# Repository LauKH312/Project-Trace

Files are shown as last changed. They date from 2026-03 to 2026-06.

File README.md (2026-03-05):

# Project Trace
Multimeter-oscilloscope made for the DTU Bsc. Introductory Project

## Project Structure
```txt
project-root/
│
├── hardware/              # KiCad
│   ├── boards/
│   │   └── main_board/
│   ├── libraries/
│   │   ├── symbols/
│   │   ├── footprints/
│   │   └── 3dmodels/
│   └── fabrication/
│
├── firmware/
│   └── trace-cube/
│
├── docs/
│   ├── architecture/
│   ├── hardware/
│   ├── firmware/
│   ├── manufacturing/
│   └── user_manual/
│
├── scripts/               # build + automation tools
├── tools/                 # dev utilities (flashers, converters)
│
├── .gitignore
├── README.md
└── VERSION
```

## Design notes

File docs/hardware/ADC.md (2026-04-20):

# ADC
The choice of ADC was a great challenge due to the limitations of microcontrollers. 
Available ADCs which sample in the tens of MS/s were to a high extent reliant on Serial LVDS, Parallel LVDS,  Serial CMOS interfaces, all of which are not available to us due to the limitations of microcontrollers.
With a greater amount of development time, the problem can be solved using an FPGA. Due to our serious time constraints this is out of the question.

Initially we had wanted to use only one ADC (the front-runner was the ADS1605). 
Later we chose to solve the problem by compromising on bit width, keeping a second ADC with high precision and no strict speed requirements for DC and slow AC measurements.%% The faster-sampling less precise ADC is named **AC-ADC** and the slower highly precise ADC is named the **DC-ADC**. %%
Due to time and cost constraints we had to revert to using one  ADC, compromising instead on speed.

%% The loss of precision for the AC-ADC is remedied by adding new elements to the signal conditioning, allowing greater voltage resolution. This includes variable offset (requiring a precise DAC),  AC coupling and more gain settings for the InAmp. 
 %%

## ADC
We identified the following ADCs to be the most suitable candidates for the AC-ADC.

| **PARAMETER** | **ADS1605** | ADS1602  | AD4001BRMZ | **ADC3542(ADC3543)** | **ADS850** |
| --- | --- | --- | --- | --- | --- |
| **Max Sampling Rate** | 5 MS/s | 2.5 MS/s | 2 MS/s | 25(65) MS/s | 10 MS/s |
| **Bit Width** | 16b | 16b | 16b | 14b | 14b |
| **VDD** | 5V | 5.0V | 1.8V | 1.8V | 5.0V |
| **VDDIO** | 3.3V | 3.3V | 3.3V | 1.8V | 3.3V |
| **Interfaces** | PCMOS | SPI | SPI | SDR,DDR,PCMOS | PCMOS |
| Cost (no VAT) | 387DKK | 151DKK | 145DKK | | |

%% In terms of bandwidth the ADC3542/ADC3543 is the superior option, providing the possibility of sampling the fastest. It is due to the need for special signal conditioning and logic level shifting needed to accommodate its 1.8V supply that it was rejected. 
Second best is the ADS850, which we initially chose, due to its okay-ish sample-rate and its easy integration, which made it suitable for this project.
The AD850 is beat by the ADS1605 on bit-depth and not surprisingly on SNR as a result. Our hope is that the extra signal conditioning will make this difference insignificant in most applications.
 %%
The 14b options were only seriously considered when designing the dual-ADC version, however using a single ADC, the low bit-depth is considered too limiting for the precision of DC measurements.
d

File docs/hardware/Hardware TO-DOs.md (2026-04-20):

# TO-DO List - Hardware
## General
- [ ] Create and assign handsolder versions for all used applicable footprints
- [x] Assign Digikey Partnumbers to all parts ordered from Mouser
%% - [ ] Consider using Global Sourcing for Mouser Parts for PCBA %%
%% - [ ] Assign JLCPCB Partnumbers to all parts ordered for assembly %%
## Front-End
### Inputs & InAmp
- [-] Decide new gain-setting/settings
- [-] Compensate for on-resistance of switches?
- [x] Design AC-Coupling Circuit
- [x] Implement circuit using new 
## Digital
### ADC
- [x] Find voltage references

- Decided against creating a external clock source.
### User Interface
- [x] Decide upon interface
Use two rotary encoders,  two pushbuttons (off-(on)), power switch. Visual feedback with screen (128x64).
- [x] Integrate display
- [x] Connect buttons and encoders

### MCU
- [x] Decide which Nucleo board to use
- [x] Create Symbols
- [x] Create Footprint
- [x] Find SRAM IC
- [x] Create symbol and footprint for SRAM if necessary
## Power
_With BMS_
- [x] Decide on battery charging solution
- [x] Add screw-terminals

## Docs
- [ ] Update docs where applicable (rev2)

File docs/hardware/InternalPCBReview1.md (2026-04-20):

# Internal PCB Review 1
## Before Submitting Your Board for PCB Design Review
- [x] Check for unrouted nets
- [x] Repour all polygons
- [?] Ensure your board has a complete silkscreen, including:
	- [-] Company logo(s)
	- [?] Product logo(s)
	- [-] Copyright notice
	- [-] Warning/Hazard label(s) and Icons
	- [x] Connectors are labeled, and pinouts are called out where relevant
	- [-] QA/Test block with barcode, blank areas for a serial number, dates, and QA/Test checkmarks
	- [x] Board name, print date, and revision number
- [!] If there are designators on the silkscreen, then check:
	- [!] Each designator is close to and clearly identifies the associated component
		- C316-C321 messy
		- C336 intersects
		- JP303 intersects
		- TP201 (VCOM) silkscreen intersect
		- R311
	- [x] All designators are only in one or two orientations
	- [x] Text size and font will remain legible after the fabrications process
	- [!] ICs have pin one clearly marked, i.e., the pin one marker is not located under another component
		- U305 unclear
		- U306 might be unclear
		- U205 ambiguous
- [x] Update the PCB from its schematics to ensure the schematic and board are synchronized
- [x] Ensure the design rule report passes with no errors
- [?] Ensure there is a design rule to catch nets with only 1 pin
- [?] Ensure you have the board outline on a mechanical layer that will go to the board fabricator
- [-] Fiducials are present for the assembly and meet these criteria:
  - [-] Three board-level fiducials are included as a minimum
  - [-] Two fiducials are diagonally opposing each other across all extremely fine-pitch components
- [-] Mounting points have sufficient clearance for the chosen washer and screw head
- [-] If an enclosure model is available, it has been tested against the board to ensure there will be no interference between the enclosure and components
- [-] All components (including mechanical items) have accurate 3D models

## Layers
- [x] Check the layer stack and substrate heights meet the fabricator's specifications (or that the fabricator can meet your specifications)
- [x] Check the copper thickness on all layers matches the target fabricator's specifications (or that there is a callout on the documentation layer for the required copper thickness)
- [x] Ensure there is at least one continuous, unbroken ground plane
- [-] If your board has controlled impedance nets, they are correctly set up both on the layer stack and in the design rules
- [x] Check if any keep-out track matches the board shape
- [?] Check any board cutouts or slots used for a keep-out barrier to prevent nets from crossing milled areas
	- GND Plane cut under ADC?

// A PCB stackup table that was created as part of your front-end engineering specifications can be helpful here as it gives a visual comparison with the data in your PCB editor. A table provided by your fabrication house or manufacturer is the best resource, such as the example shown below.

## Signal Path
- [!] Ensure that the ground plane has sufficient current-carrying vias near connectors, and voltage/return sinks
	- Connector could use more
- [-] If required/relevant, ensure voltage planes and areas have sufficient connection vias for current requirements
- [x] Ensure tracks to reference planes are sufficiently wide for current requirements
- [x] Check there are sufficient quantities of vias for the current-carrying capacity of traces
- [x] Check the minimum track widths for all current-carrying nets are sufficient. Consider if a design rule is required
	- 3V3 track about the 'coupling' text can be made wider
	- 3V3 track above JP301 label has a sharp corner
- [x] Check all ground pins have a via to the ground plane
- [x] Check there is a continuous ground plane within one signal layer of any signal trace
- [-] Check any controlled impedance traces have the correct net rules and impedance profile
- [-] Check differential pair tracks are as close together as possible
- [-] Check differential pair tracks lengths are matched
- [-] Check all high-speed signals are length matched, specifically including:
  - [-] DDR
  - [-] PCIe
  - [-] Ethernet
  - [-] LVDS
  - [-] HDMI
  - [-] USB3+
  - [-] MIPI
- [-] Check every signal trace has a constant impedance along its length. If the trace changes layer, its impedance should stay the same
- [-] Check traces longer than 1/6th of the rise or fall time of the signal have been simulated:
- [!] Check termination resistors, or another termination is present to prevent ringing or overshoots
	- ADC SCLK, DOUT, FSO lacks termination
	- SPI3 SCLK, MOSI
- [ ] Check termination resistors are in the relevant locations
- [-] Check long traces that hug other traces that have been simulated for crosstalk
	- Display traces can be spaced more before conn
- [x] Check all high-speed traces run over a continuous ground pour
- [x] Ensure that no sensitive nets run under noisy components
- [x] Check that the vias for decoupling capacitors are not shared
- [x] Each decoupling capacitor requires its own via for VCC and for GND direct to reference planes

## Components
- [x] Check all through-hole pads are set to plated if they are going to be soldered
- [ ] Check there is sufficient clearance for the following:
  - [-] For pick and place heads in production
  - [ ] For hand assembly in prototypes
  - [ ] For soldering pen tip access if any rework is required
- [x] Check bypass capacitors are placed as close to IC power pins as possible (under 15mm)
- [!] Check crystal/oscillator clock sources are as close to the IC clock pins as possible
- [!] Check termination resistors are as close to the signal source as possible
- [-] Check EMI/RFI filtering is as close to the exit point (board edge, connector, shield) as possible
- [-] Check potentiometers increase signal/voltage when turned clockwise
- [ ] Check programmable devices have accessible programming header/pads
- [-] Check no high thermal mass components (e.g., large transformers/inductors) are located next to very small components
- [ ] Check component placement prioritizes short track lengths for high-speed signals
- [-] Check there are a sufficiently large copper area for heat-sinking high-dissipation devices, including:
  - [ ] Linear regulators
  - [-] Switched-mode power supplies (including LED drivers)
  - [-] High power LEDs
  - [-] High-frequency gate drivers
  - [-] MOSFETs
  - [-] Motor drivers
  - [-] Chargers
  - [-] High-speed microprocessors
  - [-] Power amplifiers

## Testing
- [x] Check that test pads are sufficiently far from the edge of the board to allow fixturing
- [-] Check test pads do not create stubs/impedance mismatch on high-speed nets
- [x] Check that component do not obstruct access to test pads for manual testing (e.g., using an oscilloscope probe) or automated testing (e.g., using a bed of nails)
- [x] Check test pads are clearly labeled for prototypes
- [!] Check any signal needed for testing or inspection has a test point
	- 3V3, 5V missing test points...
- [x] Check test points are all located on the same side of the board, ideally:
  - [-] The bottom of the board for access using a bed of nails fixtures
  - [x] The top of the board for manual access with test equipment (e.g., oscilloscope probes)

## Protection/EMI/EMC
- [-] Check appropriate creepage and clearance rules are set for all high-voltage nets
- [x] Check if separate earth tracks/paths are necessary for ESD
- [x] Check there are decoupling capacitors next to connectors and vias that may require them
- [x] Check TVS diodes or other ESD mitigation component pads are in series with the track to the component (i.e., any ESD event must pass through the component pad before getting to a sensitive device)
- [ ] Ensure there are no track stubs/net antennas going to test points or unused connector pins
- [ ] Ensure high-speed signals are routed as directly as possible—no scenic routes
- [x] Check any track carrying over 100mA has its width calculated to ensure it is of sufficient size for the current
- [ ] If the board will be fitted within an enclosure with little or no airflow, calculate or simulate the width for an internal layer instead of an external layer
- [ ] Check if an RF shield is required anywhere on the board and if it has a sufficient footprint
- [-] If you are using a two-layer board:
	- [-] Are there any ground loops?
	- [-] Is there a ground track of sufficient size for the return current of every device?
	- [-] Is there an unbroken ground pour under every high-speed trace?
	- [-] If you have multiple grounds, ensure that they are tied together at a single point only

## Panels
- [-] Ensure that there is sufficient frame area for conveyors and clamping
- [ ] Ensure that the silkscreen includes the following:
- [-] Blanks for QA/Testing marks
- [ ] Print date
- [-] Machine name
- [-] Company name
- [-] Panel barcode
- [x] Board part number and revision
- [-] Check panel fiducials are present
- [-] Check for an origin identification mark
- [-] Check impedance/layer/other test areas are present if required
- [-] Check V Score/Milling/tab layers are present and aligned with the board if they are not in the board file
- [?] Check the panel isn't too large for the board thickness and any milling (i.e., low flexibility/bounce)

## Comments
- Reassign designators?
- Maybe write pin-out to connector?
- Ensure Correct Orientation of Screw Terminal
- PCB legs
- Eliminate gnd fill antennas - swiss-cheese the thing
- 220R Resistors (for LED) are missing PN and Footprint - ignore PN if using resistors from lab.
- Extra GND via to U306

- AAF coeff

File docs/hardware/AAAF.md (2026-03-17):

# Analog Anti-Aliasing Filter
There is an open question regarding the topology and design of the AAAF. Initially we favoured a Type II Chebyshev filter, however upon learning that this cannot be implemented on a Sallen-Key topology, we reconsider the filter design, or choose to implement it using a passive Cauer topology.
The options are as follows
- Type II Chebyshev filter implemented on a Cauer topology
- Type I Chebyshev filter implemented on a Sallen-Key topology
- Bessel filter implemented on a Sallen-Key Topology

| Type II Cheby - Cauer | Type I Cheby - Sallen-Key | Bessel - Sallen-Key |
| --- | --- | --- |
| No passband ripple | Little (possibly negligible) passband ripple | |
| | | Linear phase response |
| Possibly lower order | | Highest order solution |
| High susceptibility to component deviations (inherent to LC ladder) | Lesser susceptibility to component deviations<br>(0.1% Thin-Film R, 1% NP0 cap) | Lesser susceptibility .... |
| Not Effected by Op-Amp Bandwidth | | |
| | | |

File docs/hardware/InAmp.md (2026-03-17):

# Instrumentation Amplifier
We chose the Analog Devices AD8421 due to its high bandwidth (10MHz@G=0dB) and because we have SPICE models, which we can use for simulation. We considered assembling our own InAmp from higher bandwidth precision op-amps and diff-amps, but chose against this due to uncertainties around component tolerances. It also was unclear whether the higher bandwidth would be spent when chaining together multiple amps.

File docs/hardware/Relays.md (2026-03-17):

# Relays
We had a choice between electromechanical relays and solid-state relays.

| Electromechanical Relay | Solid-State Relay |
| --- | --- |
| Low on resistance $R_{on} < 500\mathrm{m\Omega}$ | Higher on-resistance $>2 \Omega$ |
| Can block high voltages | ~~Generally limited by voltage~~ |
| Large | Roughly SOIC-Sized |
| Switching requires special consideration | Switchable with GPIO |
| | |
Due to the large resistances in the attenuator we deemed the 2R5 on resistance of the Panasonic AQW280SX to be negligible, however the ammeter uses a 100m shunt resistor, which would be greatly impacted by this. We chose to buffer the voltage over the shunt-resistor to eliminate this probem.

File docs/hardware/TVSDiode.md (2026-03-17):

# TVS Diode
According to a brief search on Mouser, many TVS have a leakage around $1\mathrm{\mu A}$.
For the ammeter this is a non-issue, as this is many orders of magnitude under the maximum of 200mA in the range.

However in the voltmeter this poses an issue

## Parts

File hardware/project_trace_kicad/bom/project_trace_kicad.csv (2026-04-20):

Reference | Value | Qty | Extra | DigikeyPN | DNP | Exclude from BOM | Exclude from Board | Footprint | Datasheet | MouserPN
U305 | 625L3C040M00000 | 1 |  | 110-625L3C040M00000CT-ND |  |  |  | ProjectTraceFootprints:IC_625L3C040M00000_CTS-M
R211 | 8k98 | 1 | 0.1% | 13-RT0603BRD078K98LCT-ND |  |  |  | Resistor_SMD:R_0603_1608Metric_Pad0.98x0.95mm_HandSolder
R205,R213 | 193R | 2 |  | 13-RT0603DRE07193RLCT-ND |  |  |  | Resistor_SMD:R_0603_1608Metric_Pad0.98x0.95mm_HandSolder
D201 | SMAJ250A | 1 |  | 13-SMAJ250A/TR13CT-ND |  |  |  | Diode_SMD:D_SMA_Handsoldering
U302 | MCP6499T | 1 |  | 150-MCP6499T-E/SLCT-ND |  |  |  | ProjectTraceFootprints:SOIC-14_3.9x8.7mm_P1.27mm_Handsolder | http://www.ti.com/lit/ds/symlink/lm2902-n.pdf
R305,R307 | 37k | 2 |  | 2019-RN73R1JTTD3702F100CT-ND |  |  |  | Resistor_SMD:R_0603_1608Metric_Pad0.98x0.95mm_HandSolder
R212 | 111R | 1 |  | 2019-RN73R1JTTD1110B25CT-ND |  |  |  | Resistor_SMD:R_0603_1608Metric_Pad0.98x0.95mm_HandSolder
R201 | 100m | 1 | 0.5% 1W5 | 2019-SLW1TTER100DCT-ND |  |  |  | Resistor_SMD:R_2512_6332Metric_Pad1.40x3.35mm_HandSolder | https://www.koaspeer.com/pdfs/SLW07-SLW1-SLN3-SLN5.pdf#page=1.00 | SLW1TTER100D
PH501,PH502 | PH for Nucleo | 2 |  | 2057-PH2-80-UA-ND |  |  | Excluded from board
U203 | AQW280SX | 1 |  | 255-5713-1-ND |  |  |  | ProjectTraceFootprints:AQW282SX | https://www.mouser.com/catalog/specsheets/AQW280S[1].pdf | 769-AQW280SX
U204 | AQW282SX | 1 |  | 255-AQW282SXCT-ND |  |  |  | ProjectTraceFootprints:AQW282SX | https://mm.digikey.com/Volume0/opasdata/d220001/medias/docus/2807/AQY%2CW28xS_DS.pdf
U202 | SN74LVC2G14DBV | 1 |  | 296-13010-1-ND |  |  |  | Package_TO_SOT_SMD:SOT-23-6_Handsoldering | https://www.ti.com/lit/ds/symlink/sn74lvc2g14.pdf
U401 | UA78M33QDCYRQ1 | 1 |  | 296-13424-1-ND |  |  |  | Package_TO_SOT_SMD:SOT-223-3_TabPin2 | https://www.ti.com/lit/gpn/UA78M-Q1
U303 | ADS1602 | 1 |  | 296-17890-1-ND |  |  |  | ProjectTraceFootprints:LQFP-48_7x7_Pitch0.5mm - PFB0048A | https://www.ti.com/lit/ds/symlink/ads1602.pdf
U206 | TS5A23159DGS | 1 |  | 296-18598-1-ND |  |  |  | Package_SO:TSSOP-10_3x3mm_P0.5mm | http://www.ti.com/lit/ds/symlink/ts5a23159.pdf
U205,U207 | OPA2837IRUNT | 2 |  | 296-53042-1-ND |  |  |  | ProjectTraceFootprints:OPA2837IRUNT-Handsolder
U201 | TLE2426xLP | 1 |  | 296-TLE2426CLPRCT-ND |  |  |  | Package_TO_SOT_THT:TO-92_Inline_Wide | http://www.ti.com/lit/ds/symlink/tle2426.pdf
C316,C317,C318 | 100p | 3 | C0G | 311-1069-1-ND |  |  |  | Capacitor_SMD:C_0603_1608Metric_Pad1.08x0.95mm_HandSolder
C213 | 680p | 1 | C0G | 311-1425-1-ND |  |  |  | Capacitor_SMD:C_0603_1608Metric_Pad1.08x0.95mm_HandSolder
C211 | 300p | 1 | C0G | 311-3967-1-ND |  |  |  | Capacitor_SMD:C_0603_1608Metric_Pad1.08x0.95mm_HandSolder
C202,C205,C208,C210,C214,C305,C307,C310,C311,C313,C314,C315,C319,C320,C321,C324,C326,C327,C328,C331,C334,C338,C339 | 100n | 23 | 25V | 399-C0603C104K3RACTUCT-ND |  |  |  | Capacitor_SMD:C_0603_1608Metric_Pad1.08x0.95mm_HandSolder
C301,C302,C306,C308,C312,C325,C329,C335,C337 | 1u | 9 | 16V | 399-C0603C105K4RACTUCT-ND |  |  |  | Capacitor_SMD:C_0603_1608Metric_Pad1.08x0.95mm_HandSolder
R202 | 1M8 | 1 | 0.1% | 408-2026-1-ND |  |  |  | Resistor_SMD:R_0805_2012Metric_Pad1.20x1.40mm_HandSolder
C201,C203,C204,C207,C209,C212,C303,C309,C322,C323,C330,C333,C336 | 10u | 13 |  | 490-10516-1-ND |  |  |  | Capacitor_SMD:C_0805_2012Metric_Pad1.18x1.45mm_HandSolder
C206 | 10u | 1 | X7R | 490-10516-1-ND |  |  |  | Capacitor_SMD:C_0805_2012Metric_Pad1.18x1.45mm_HandSolder
U301 | ADA4950-1 | 1 |  | 505-ADA4950-1YCPZ-R7CT-ND |  |  |  | ProjectTraceFootprints:ADA4950-QFN-16_EP_3.1x3.1_Pitch0.5mm | https://www.analog.com/media/en/technical-documentation/data-sheets/ADA4950-1_4950-2.pdf
U402 | AMS1117-5.0 | 1 |  | 5272-AMS1117-5.0CT-ND |  |  |  | Package_TO_SOT_SMD:SOT-223-3_TabPin2 | http://www.advanced-monolithic.com/pdf/ds1117.pdf
U304 | LM4040DBZ-4.1 | 1 |  | 576-2568-1-ND |  |  |  | Package_TO_SOT_SMD:SOT-23_Handsoldering | http://www.ti.com/lit/ds/symlink/lm4040-n.pdf
J204,J403 | Screw_Terminal_01x04 | 2 |  | 732-691210910004-ND |  |  |  | ProjectTraceFootprints:691210910004 |  | 710-691210910004
DZ201,DZ202 | EZA-EG3A50AV | 2 |  | P13682CT-ND |  |  |  | Diode_SMD:D_0603_1608Metric_Pad1.05x0.95mm_HandSolder |  | 667-EZA-EG3A50AV
J205 | Conn_Coaxial | 1 |  | WM14063-ND |  |  |  | ProjectTraceFootprints:BNC_Female_0731385003
R209,R303,R304,R601,R602,R603,R604 | 10k | 7 |  | YAG1236CT-ND |  |  |  | Resistor_SMD:R_0603_1608Metric_Pad0.98x0.95mm_HandSolder
R206,R208,R210 | 1k | 3 | 0.1% | YAG1237CT-ND |  |  |  | Resistor_SMD:R_0603_1608Metric_Pad0.98x0.95mm_HandSolder
R203,R311 | 180K | 2 | 0.1% | YAG1548CT-ND |  |  |  | Resistor_SMD:R_0603_1608Metric_Pad0.98x0.95mm_HandSolder
R204 | 20K | 1 | 0.1% | YAG1582CT-ND |  |  |  | Resistor_SMD:R_0603_1608Metric_Pad0.98x0.95mm_HandSolder
R301,R302,R306,R308,R309,R310,R501,R504,R505 | 24R9 | 9 |  | YAG4511CT-ND |  |  |  | Resistor_SMD:R_0603_1608Metric_Pad0.98x0.95mm_HandSolder

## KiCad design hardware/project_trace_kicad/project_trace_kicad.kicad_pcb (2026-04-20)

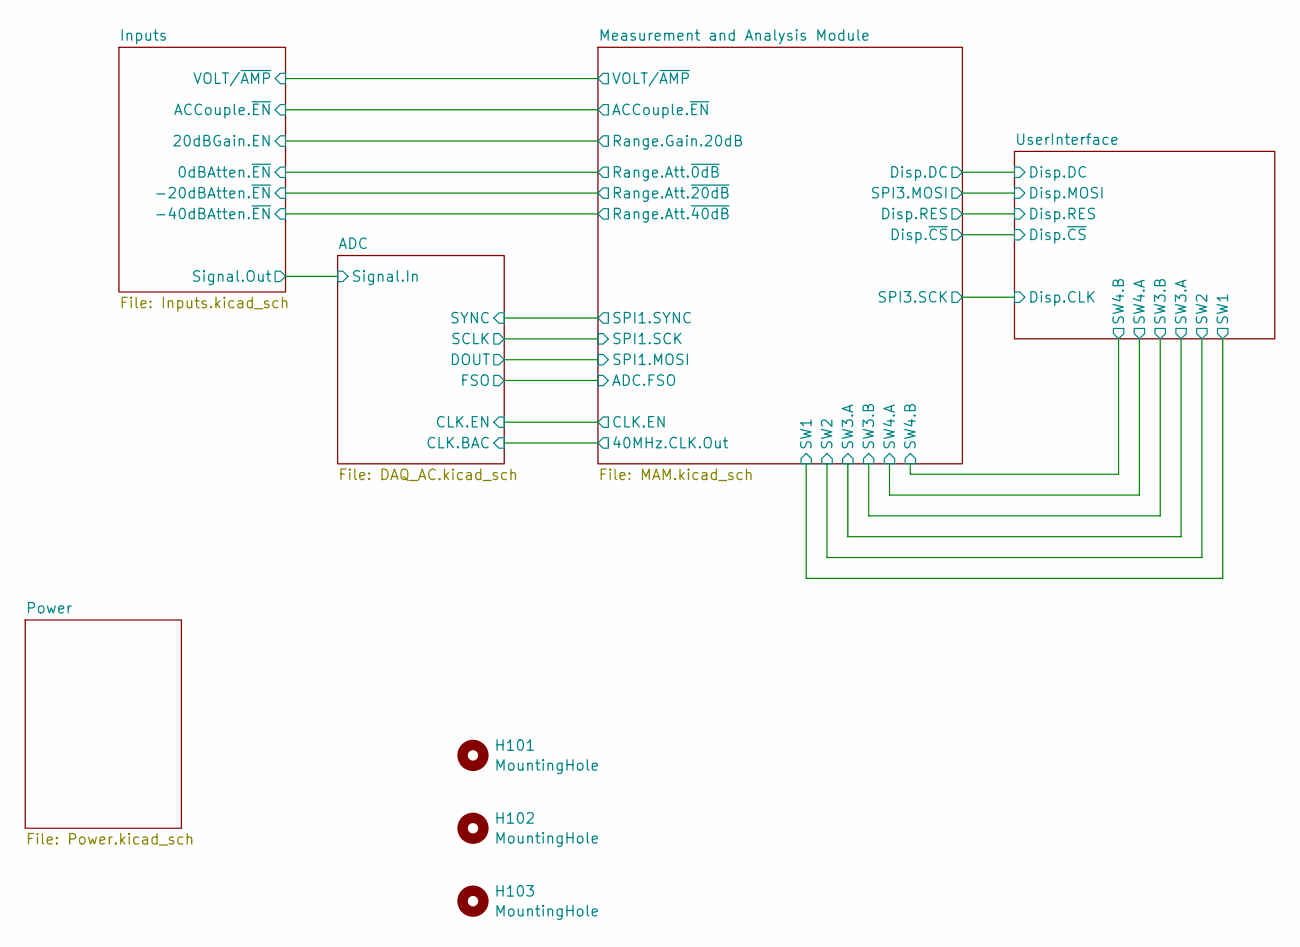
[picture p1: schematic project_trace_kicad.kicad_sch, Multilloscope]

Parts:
H101, H102, H103: MountingHole; MountingHole_4.3mm_M4_DIN965; DigikeyPN N/A

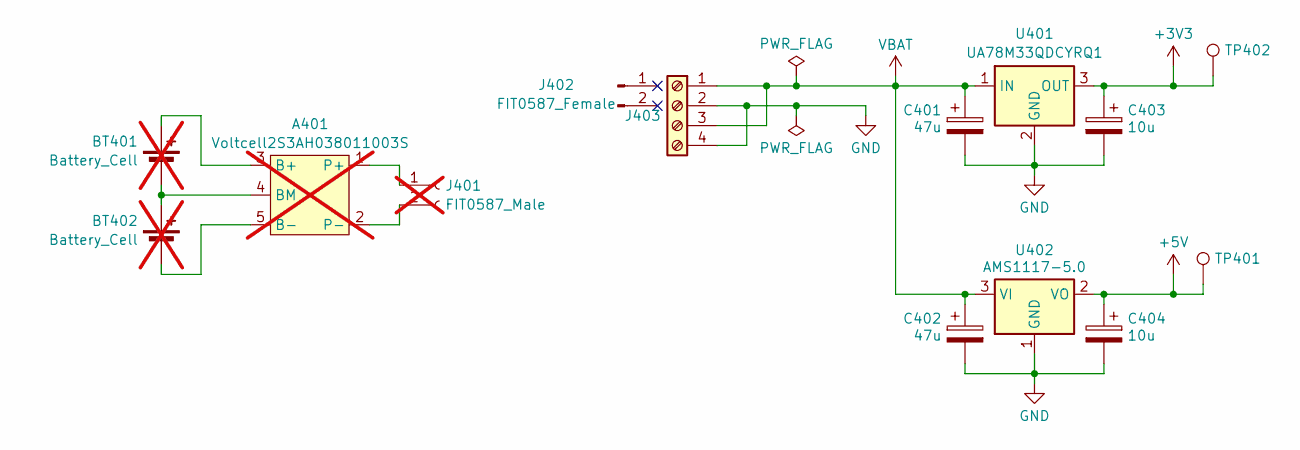
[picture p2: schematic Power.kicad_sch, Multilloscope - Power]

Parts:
A401: Voltcell2S3AH038011003S; DigikeyPN N/A; not fitted
BT401, BT402: Battery_Cell; DigikeyPN N/A; not fitted
C401, C402: 47u; CP_Radial_D6.3mm_P2.50mm; DigikeyPN N/A
C403, C404: 10u; CP_Radial_D6.3mm_P2.50mm; DigikeyPN N/A
J401: FIT0587_Male; DigikeyPN N/A; not fitted
J402: FIT0587_Female; DigikeyPN N/A
J403: Screw_Terminal_01x04; 691210910004; DigikeyPN 732-691210910004-ND
TP401, TP402: TestPoint; TestPoint_Pad_1.5x1.5mm; DigikeyPN N/A
U401: UA78M33QDCYRQ1; SOT-223-3_TabPin2; DigikeyPN 296-13424-1-ND
U402: AMS1117-5.0; SOT-223-3_TabPin2; DigikeyPN 5272-AMS1117-5.0CT-ND

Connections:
+3V3: C403.1, TP402.1 (1_1), U401.3 (OUT); also elsewhere on the board
+5V: C404.1, TP401.1 (1_1), U402.2 (VO); also elsewhere on the board
GND: C401.2, C402.2, C403.2, C404.2, J403.2, J403.4, U401.2 (GND), U402.1 (GND); also elsewhere on the board
unnamed: A401.1 (P+), J401.1
unnamed: A401.2 (P-), J401.2
unnamed: A401.3 (B+), BT401.1 (+)
unnamed: A401.4 (BM), BT401.2 (-), BT402.1 (+)
unnamed: A401.5 (B-), BT402.2 (-)
VBAT: C401.1, C402.1, J403.1, J403.3, U401.1 (IN), U402.3 (VI)

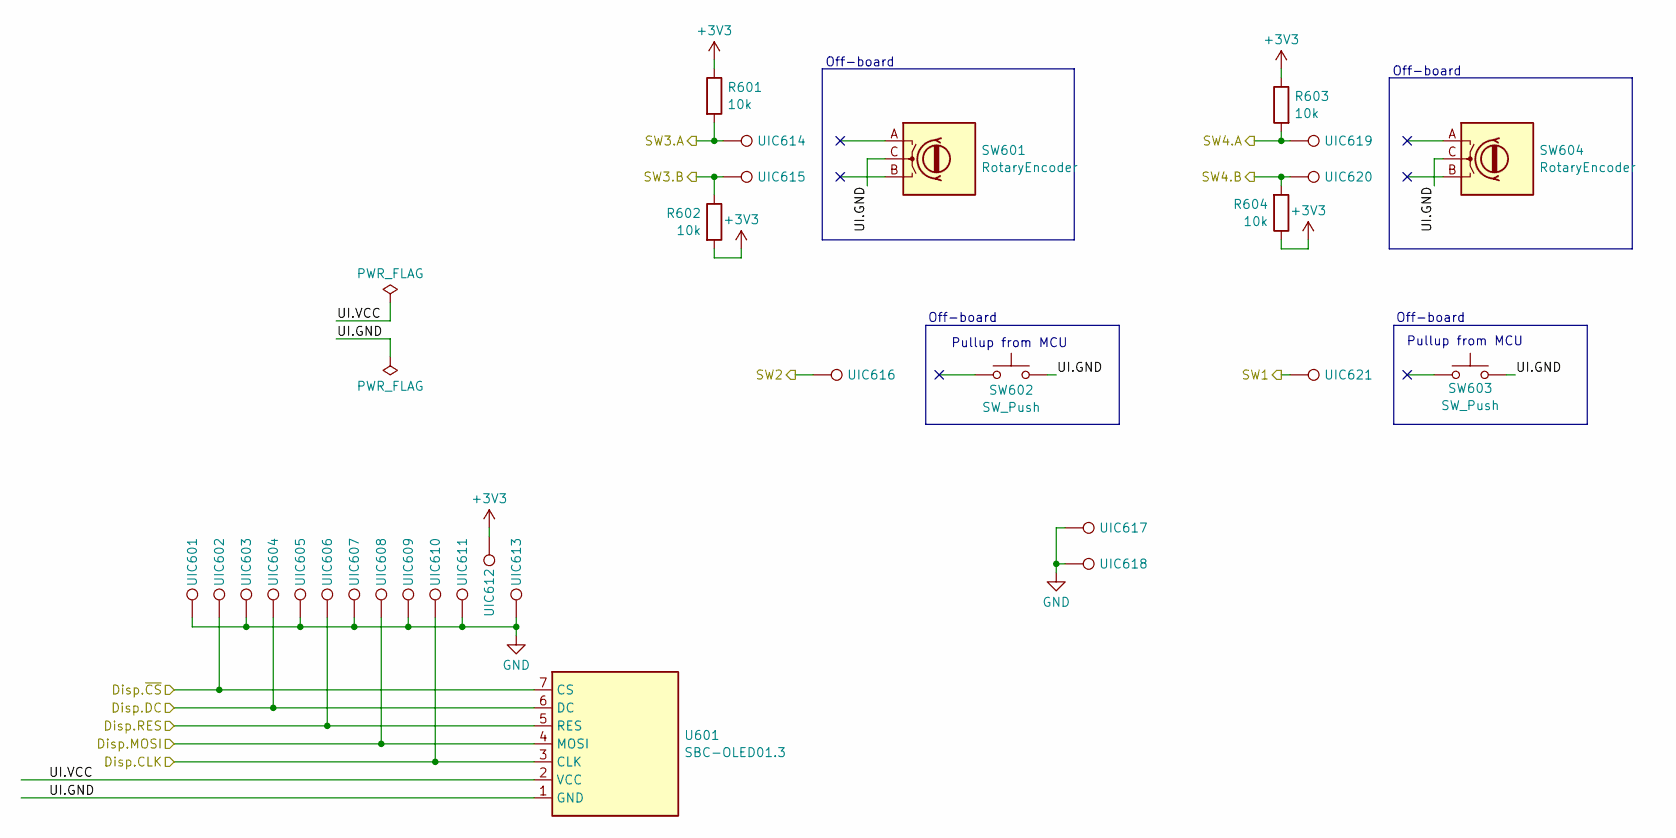
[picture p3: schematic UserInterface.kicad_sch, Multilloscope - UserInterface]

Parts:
R601, R602, R603, R604: 10k; R_0603_1608Metric_Pad0.98x0.95mm_HandSolder; DigikeyPN YAG1236CT-ND
SW601, SW604: RotaryEncoder; DigikeyPN N/A
SW602, SW603: SW_Push; DigikeyPN N/A
U601: SBC-OLED01.3; DigikeyPN N/A
UIC601, UIC602, UIC603, UIC604, UIC605, UIC606, UIC607, UIC608, UIC609, UIC610, UIC611, UIC612, UIC613, UIC614, UIC615, UIC616, UIC617, UIC618, UIC619, UIC620, UIC621: UIconnector; TestPoint_Pad_D2.5mm; DigikeyPN N/A

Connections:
+3V3: R601.1, R602.2, R603.1, R604.1, UIC612.1 (1_1); also elsewhere on the board
/Measurement and Analysis Module/Disp.DC: U601.6 (DC), UIC604.1 (1_1); also elsewhere on the board
/Measurement and Analysis Module/Disp.RES: U601.5 (RES), UIC606.1 (1_1); also elsewhere on the board
/Measurement and Analysis Module/Disp.~CS: U601.7 (CS), UIC602.1 (1_1); also elsewhere on the board
/Measurement and Analysis Module/SPI3.MOSI: U601.4 (MOSI), UIC608.1 (1_1); also elsewhere on the board
/Measurement and Analysis Module/SPI3.SCK: U601.3 (CLK), UIC610.1 (1_1); also elsewhere on the board
/Measurement and Analysis Module/SW1: UIC621.1 (1_1); also elsewhere on the board
/Measurement and Analysis Module/SW2: UIC616.1 (1_1); also elsewhere on the board
/Measurement and Analysis Module/SW3.A: R601.2, UIC614.1 (1_1); also elsewhere on the board
/Measurement and Analysis Module/SW3.B: R602.1, UIC615.1 (1_1); also elsewhere on the board
/Measurement and Analysis Module/SW4.A: R603.2, UIC619.1 (1_1); also elsewhere on the board
/Measurement and Analysis Module/SW4.B: R604.2, UIC620.1 (1_1); also elsewhere on the board
GND: UIC601.1 (1_1), UIC603.1 (1_1), UIC605.1 (1_1), UIC607.1 (1_1), UIC609.1 (1_1), UIC611.1 (1_1), UIC613.1 (1_1), UIC617.1 (1_1), UIC618.1 (1_1); also elsewhere on the board
unnamed: SW601.C, SW602.1, SW603.2, SW604.C, U601.1 (GND)

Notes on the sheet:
Pullup from MCU
Off-board

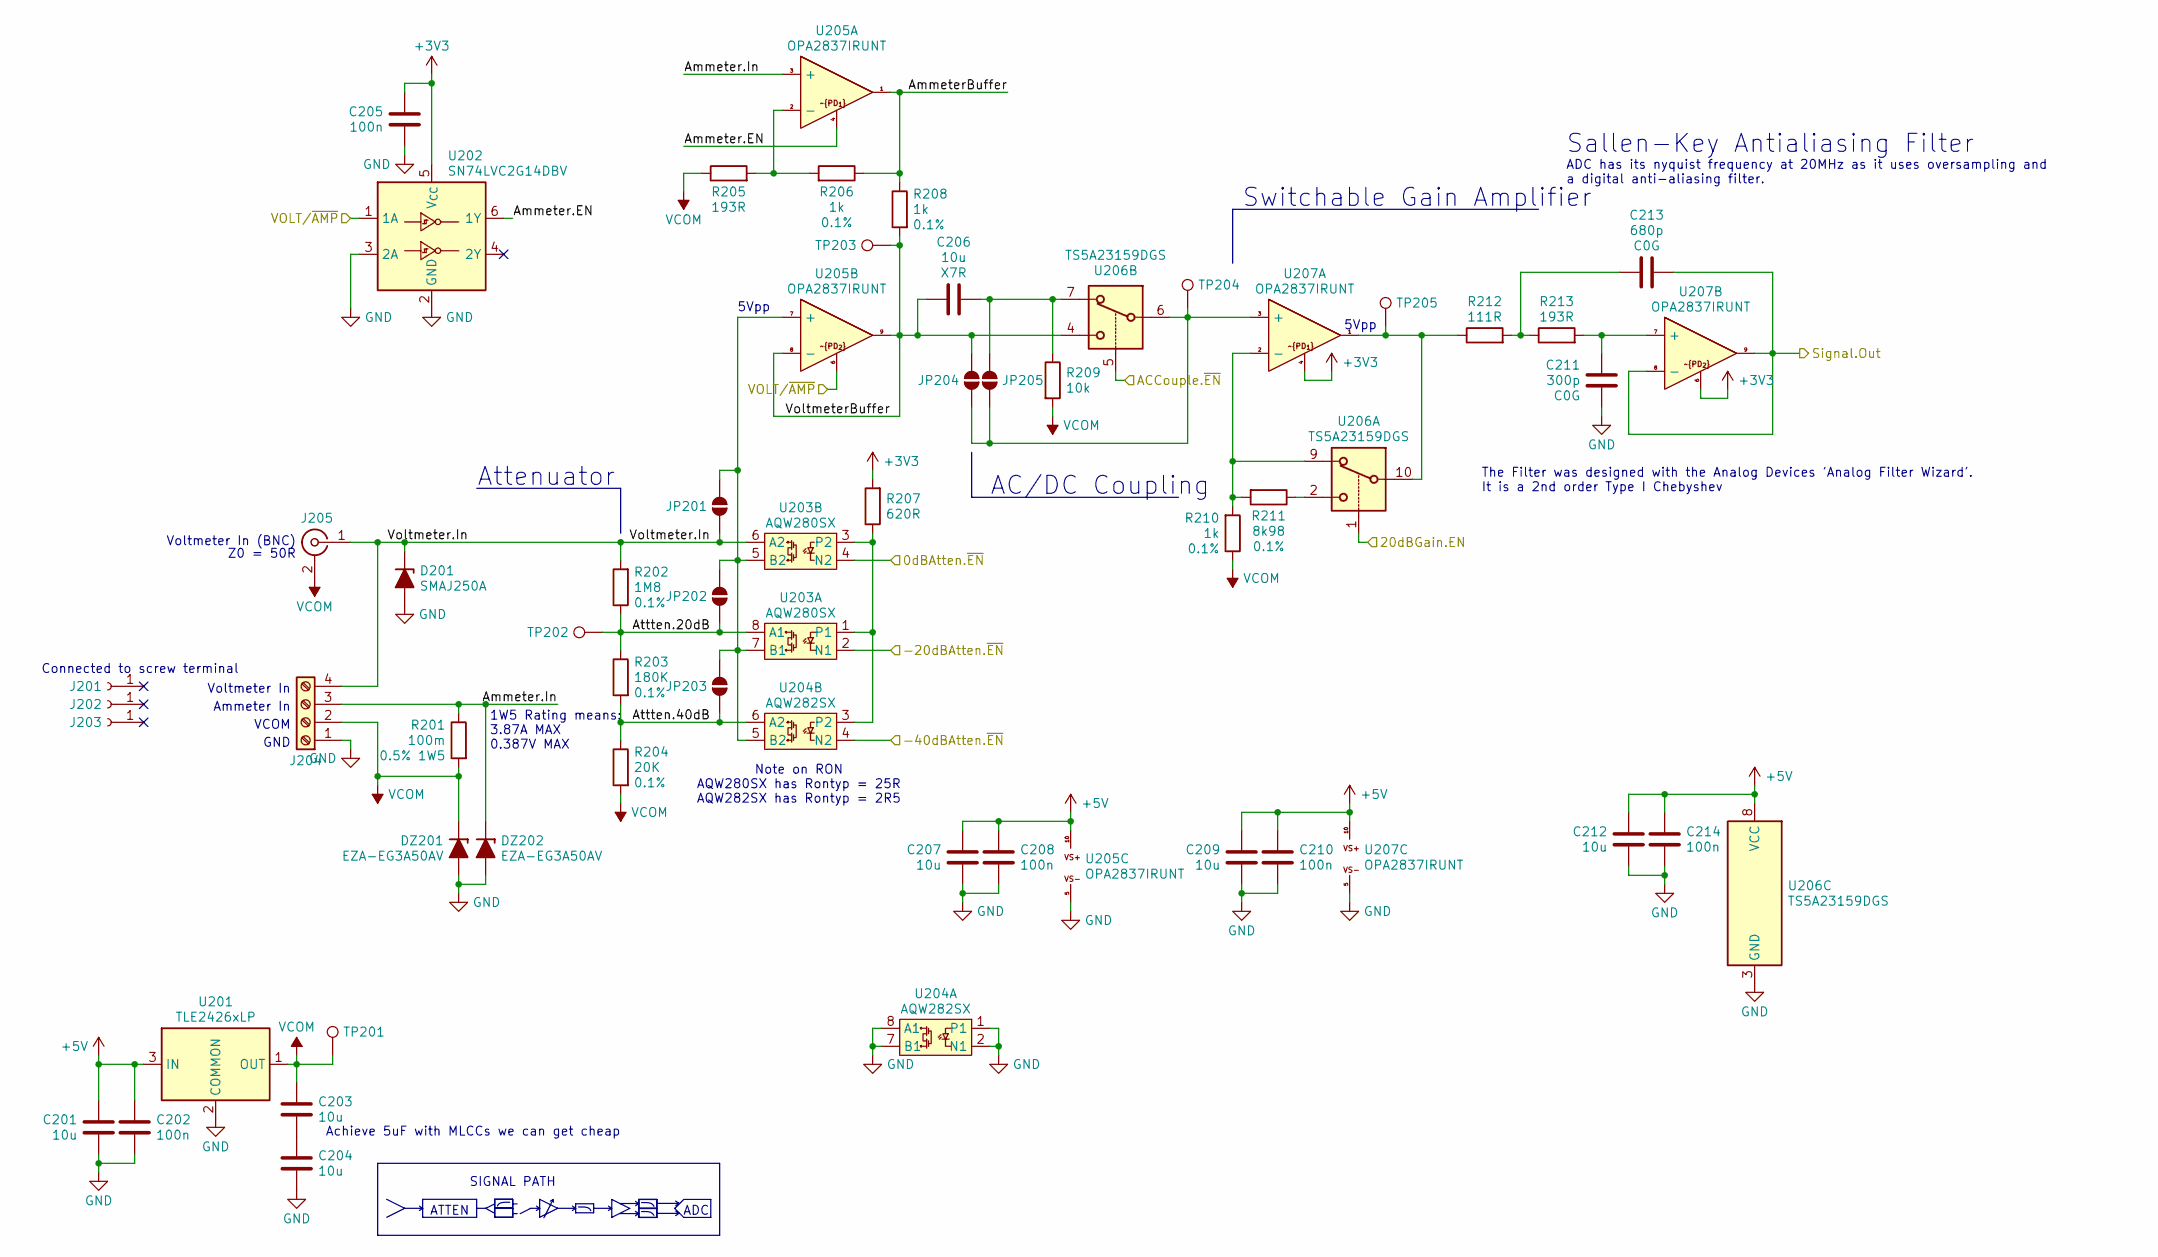
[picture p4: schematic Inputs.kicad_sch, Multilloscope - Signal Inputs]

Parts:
C201, C203, C204, C206, C207, C209, C212: 10u; C_0805_2012Metric_Pad1.18x1.45mm_HandSolder; DigikeyPN 490-10516-1-ND
C202, C205, C208, C210, C214: 100n; C_0603_1608Metric_Pad1.08x0.95mm_HandSolder; DigikeyPN 399-C0603C104K3RACTUCT-ND
C211: 300p; C_0603_1608Metric_Pad1.08x0.95mm_HandSolder; DigikeyPN 311-3967-1-ND
C213: 680p; C_0603_1608Metric_Pad1.08x0.95mm_HandSolder; DigikeyPN 311-1425-1-ND
D201: SMAJ250A; D_SMA_Handsoldering; DigikeyPN 13-SMAJ250A/TR13CT-ND
DZ201, DZ202: EZA-EG3A50AV; D_0603_1608Metric_Pad1.05x0.95mm_HandSolder; MouserPN 667-EZA-EG3A50AV
J201, J202, J203: Conn_01x01_Socket; DigikeyPN N/A
J204: Screw_Terminal_01x04; 691210910004; MouserPN 710-691210910004
J205: Conn_Coaxial; BNC_Female_0731385003; DigikeyPN WM14063-ND
JP201, JP202, JP203, JP204, JP205: SolderJumper_2_Open; SolderJumper-2_P1.3mm_Open_RoundedPad1.0x1.5mm; DigikeyPN N/A
R201: 100m; R_2512_6332Metric_Pad1.40x3.35mm_HandSolder; MouserPN SLW1TTER100D
R202: 1M8; R_0805_2012Metric_Pad1.20x1.40mm_HandSolder; DigikeyPN 408-2026-1-ND
R203: 180K; R_0603_1608Metric_Pad0.98x0.95mm_HandSolder; DigikeyPN YAG1548CT-ND
R204: 20K; R_0603_1608Metric_Pad0.98x0.95mm_HandSolder; DigikeyPN YAG1582CT-ND
R205, R213: 193R; R_0603_1608Metric_Pad0.98x0.95mm_HandSolder; DigikeyPN 13-RT0603DRE07193RLCT-ND
R206, R208, R210: 1k; R_0603_1608Metric_Pad0.98x0.95mm_HandSolder; DigikeyPN YAG1237CT-ND
R207: 620R; R_Axial_DIN0207_L6.3mm_D2.5mm_P10.16mm_Horizontal; DigikeyPN N/A
R209: 10k; R_0603_1608Metric_Pad0.98x0.95mm_HandSolder; DigikeyPN YAG1236CT-ND
R211: 8k98; R_0603_1608Metric_Pad0.98x0.95mm_HandSolder; DigikeyPN 13-RT0603BRD078K98LCT-ND
R212: 111R; R_0603_1608Metric_Pad0.98x0.95mm_HandSolder; DigikeyPN 2019-RN73R1JTTD1110B25CT-ND
TP201, TP202, TP203, TP204, TP205: TestPoint; TestPoint_Pad_1.5x1.5mm; DigikeyPN N/A
U201: TLE2426xLP; TO-92_Inline_Wide; DigikeyPN 296-TLE2426CLPRCT-ND
U202: SN74LVC2G14DBV; SOT-23-6_Handsoldering; DigikeyPN 296-13010-1-ND
U203: AQW280SX; AQW282SX; MouserPN 769-AQW280SX
U204: AQW282SX; DigikeyPN 255-AQW282SXCT-ND
U205, U207: OPA2837IRUNT; OPA2837IRUNT-Handsolder; DigikeyPN 296-53042-1-ND
U206: TS5A23159DGS; TSSOP-10_3x3mm_P0.5mm; DigikeyPN 296-18598-1-ND

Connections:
+3V3: C205.1, R207.2, U202.5 (V_{CC}), U207.4, U207.6; also elsewhere on the board
+5V: C201.2, C202.1, C207.2, C208.1, C209.2, C210.1, C212.2, C214.1, U201.3 (IN), U205.10, U206.8 (VCC), U207.10; also elsewhere on the board
/ADC/Signal.In: C213.2, U207.8 (-), U207.9; also elsewhere on the board
/Inputs/0dBAtten.~EN: U203.4 (N2); also elsewhere on the board
/Inputs/20dBGain.EN: U206.1; also elsewhere on the board
/Inputs/-20dBAtten.~EN: U203.2 (N1); also elsewhere on the board
/Inputs/-40dBAtten.~EN: U204.4 (N2); also elsewhere on the board
/Inputs/ACCouple.~EN: U206.5; also elsewhere on the board
/Inputs/Ammeter.EN: U202.6 (1Y), U205.4
/Inputs/Ammeter.In: DZ202.1 (K), J204.3, R201.1, U205.3 (+)
/Inputs/AmmeterBuffer: R206.1, R208.1, U205.1
/Inputs/Attten.20dB: JP202.1 (A), R202.1, R203.1, TP202.1 (1_1), U203.8 (A1)
/Inputs/Attten.40dB: JP203.1 (A), R203.2, R204.1, U204.6 (A2)
/Inputs/VOLT/~AMP: U202.1 (1A), U205.6; also elsewhere on the board
/Inputs/Voltmeter.In: D201.1 (K), J204.4, J205.1 (In), JP201.1 (A), R202.2, U203.6 (A2)
/Inputs/VoltmeterBuffer: C206.2, JP204.1 (A), R208.2, TP203.1 (1_1), U205.8 (-), U205.9, U206.4
GND: C201.1, C202.2, C204.1, C205.2, C207.1, C208.2, C209.1, C210.2, C211.1, C212.1, C214.2, D201.2 (A), DZ201.2 (A), DZ202.2 (A), J204.1, U201.2 (COMMON), U202.2 (GND), U202.3 (2A), U204.1, U204.2 (N1), U204.7 (B1), U204.8 (A1), U205.5, U206.3 (GND), U207.5; also elsewhere on the board
unnamed: C203.1, C204.2
unnamed: C213.1, R212.2, R213.1
unnamed: JP201.2 (B), JP202.2 (B), JP203.2 (B), U203.5 (B2), U203.7 (B1), U204.5 (B2), U205.7 (+)
unnamed: JP204.2 (B), JP205.2 (B), TP204.1 (1_1), U206.6, U207.3 (+)
unnamed: C206.1, JP205.1 (A), R209.1, U206.7
unnamed: R211.1, U206.2
unnamed: R212.1, TP205.1 (1_1), U206.10, U207.1
unnamed: R207.1, U203.1, U203.3 (P2), U204.3 (P2)
unnamed: R205.2, R206.2, U205.2 (-)
unnamed: R210.2, R211.2, U206.9, U207.2 (-)
unnamed: C211.2, R213.2, U207.7 (+)
VCOM: C203.2, DZ201.1 (K), J204.2, J205.2 (Ext), R201.2, R204.2, R205.1, R209.2, R210.1, TP201.1 (1_1), U201.1 (OUT); also elsewhere on the board

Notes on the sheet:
ADC has its nyquist frequency at 20MHz as it uses oversampling and a digital anti-aliasing filter.
GND
Voltmeter In
Attenuator
VCOM
The Filter was designed with the Analog Devices 'Analog Filter Wizard'. It is a 2nd order Type I Chebyshev
Achieve 5uF with MLCCs we can get cheap
Note on RON AQW280SX has Rontyp = 25R AQW282SX has Rontyp = 2R5
Z0 = 50R
ADC
ATTEN
5Vpp
1W5 Rating means: 3.87A MAX 0.387V MAX
Ammeter In
AC/DC Coupling
Switchable Gain Amplifier
SIGNAL PATH
Sallen-Key Antialiasing Filter
Connected to screw terminal
Voltmeter In (BNC)

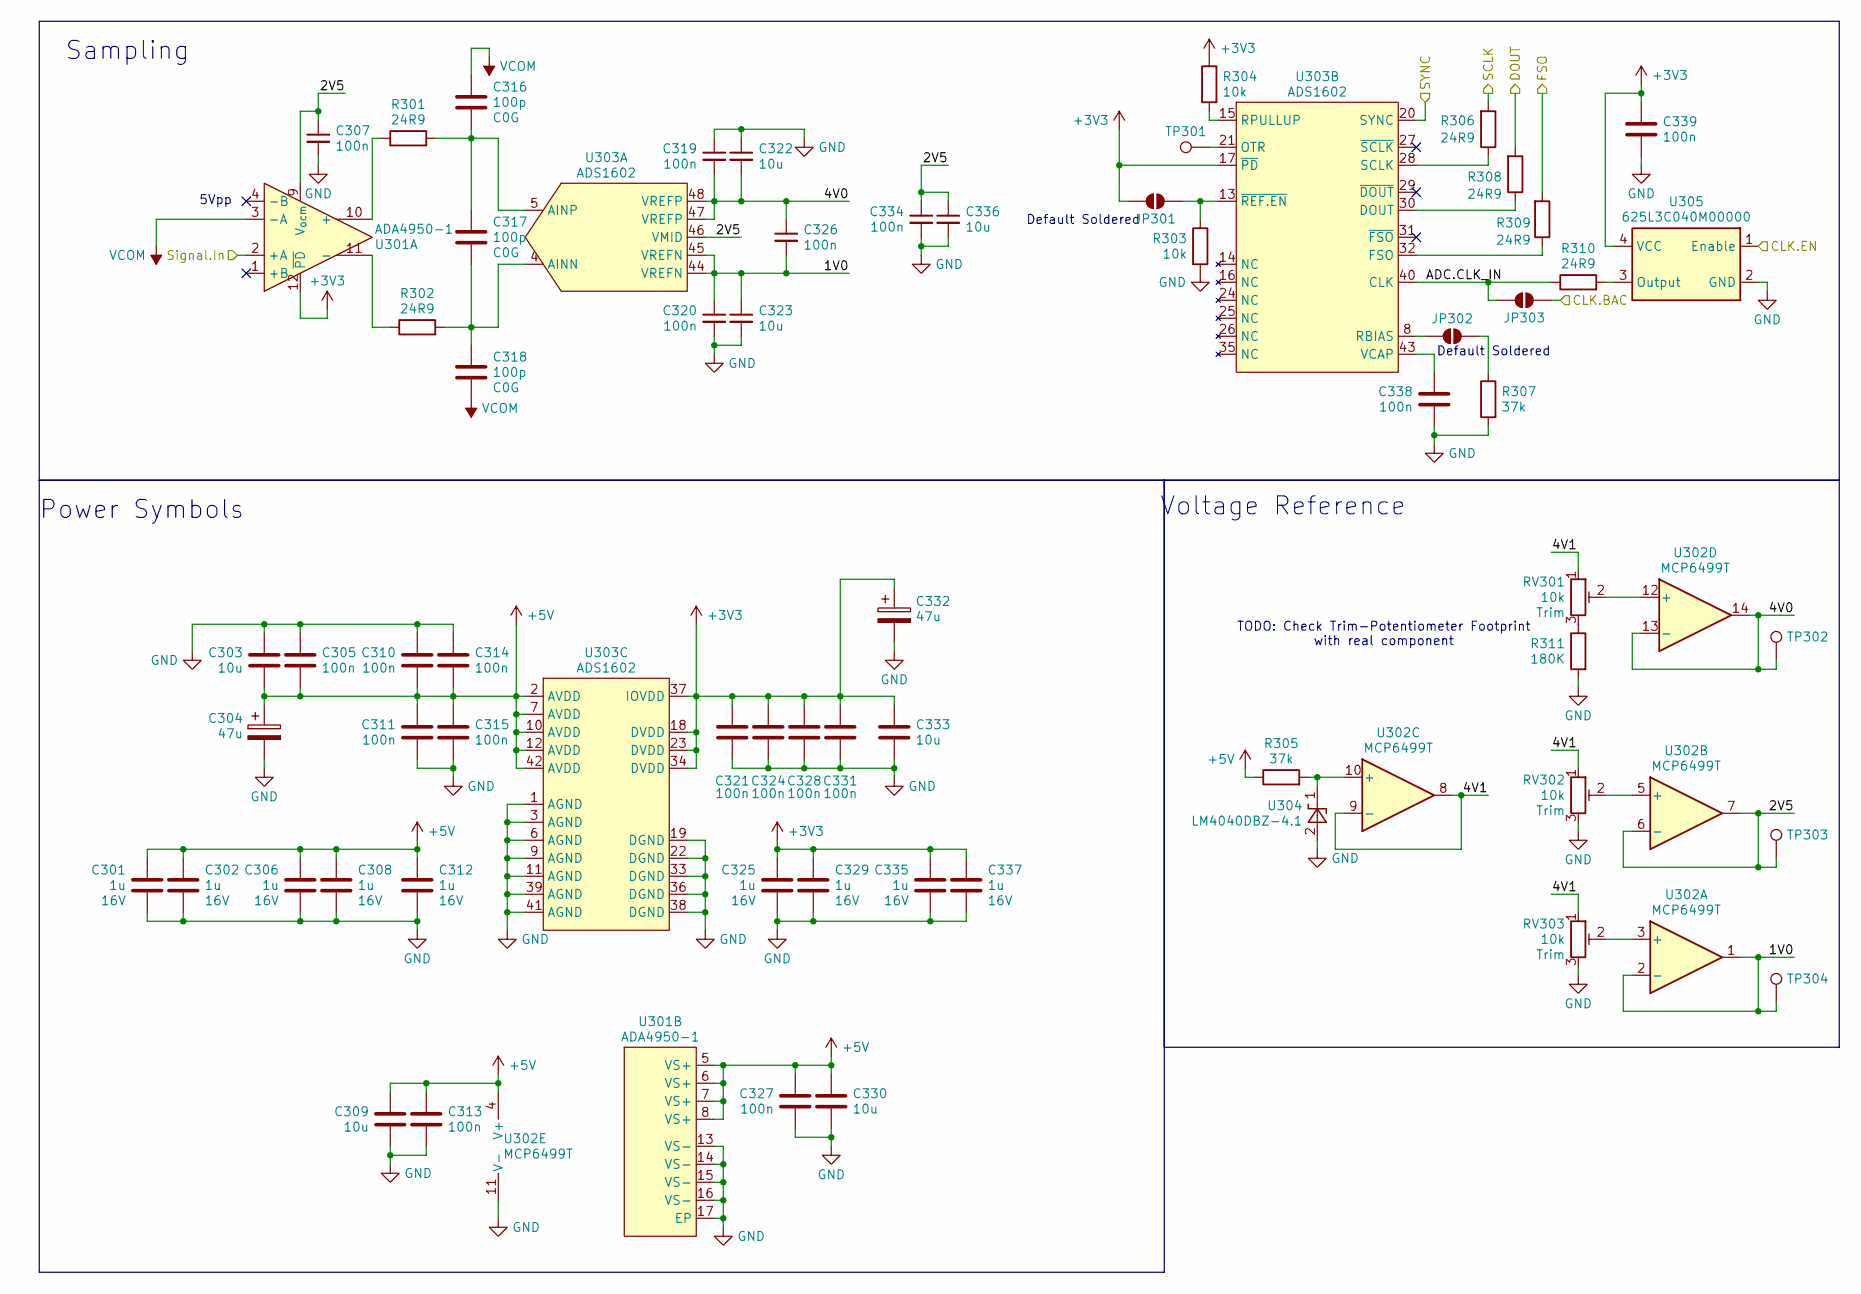
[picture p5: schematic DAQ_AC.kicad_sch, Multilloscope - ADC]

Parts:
C301, C302, C306, C308, C312, C325, C329, C335, C337: 1u; C_0603_1608Metric_Pad1.08x0.95mm_HandSolder; DigikeyPN 399-C0603C105K4RACTUCT-ND
C303, C309, C322, C323, C330, C333, C336: 10u; C_0805_2012Metric_Pad1.18x1.45mm_HandSolder; DigikeyPN 490-10516-1-ND
C304, C332: 47u; CP_Radial_D6.3mm_P2.50mm; DigikeyPN N/A
C305, C307, C310, C311, C313, C314, C315, C319, C320, C321, C324, C326, C327, C328, C331, C334, C338, C339: 100n; C_0603_1608Metric_Pad1.08x0.95mm_HandSolder; DigikeyPN 399-C0603C104K3RACTUCT-ND
C316, C317, C318: 100p; C_0603_1608Metric_Pad1.08x0.95mm_HandSolder; DigikeyPN 311-1069-1-ND
JP301, JP302, JP303: SolderJumper_2_Open; SolderJumper-2_P1.3mm_Open_RoundedPad1.0x1.5mm; DigikeyPN N/A
R301, R302, R306, R308, R309, R310: 24R9; R_0603_1608Metric_Pad0.98x0.95mm_HandSolder; DigikeyPN YAG4511CT-ND
R303, R304: 10k; R_0603_1608Metric_Pad0.98x0.95mm_HandSolder; DigikeyPN YAG1236CT-ND
R305, R307: 37k; R_0603_1608Metric_Pad0.98x0.95mm_HandSolder; DigikeyPN 2019-RN73R1JTTD3702F100CT-ND
R311: 180K; R_0603_1608Metric_Pad0.98x0.95mm_HandSolder; DigikeyPN YAG1548CT-ND
RV301, RV302, RV303: 10k; Potentiometer_Bourns_3266W_Vertical; DigikeyPN N/A
TP301, TP302, TP303, TP304: TestPoint; TestPoint_Pad_1.5x1.5mm; DigikeyPN N/A
U301: ADA4950-1; ADA4950-QFN-16_EP_3.1x3.1_Pitch0.5mm; DigikeyPN 505-ADA4950-1YCPZ-R7CT-ND
U302: MCP6499T; SOIC-14_3.9x8.7mm_P1.27mm_Handsolder; DigikeyPN 150-MCP6499T-E/SLCT-ND
U303: ADS1602; LQFP-48_7x7_Pitch0.5mm - PFB0048A; DigikeyPN 296-17890-1-ND
U304: LM4040DBZ-4.1; SOT-23_Handsoldering; DigikeyPN 576-2568-1-ND
U305: 625L3C040M00000; IC_625L3C040M00000_CTS-M; DigikeyPN 110-625L3C040M00000CT-ND

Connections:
+3V3: C321.2, C324.2, C325.2, C328.2, C329.2, C331.2, C332.1, C333.2, C335.2, C337.2, C339.2, JP301.2 (B), R304.1, U301.12 (~PD), U303.17 (~PD), U303.18 (DVDD), U303.23 (DVDD), U303.34 (DVDD), U303.37 (IOVDD), U305.4 (VCC); also elsewhere on the board
+5V: C301.2, C302.2, C303.1, C304.1, C305.1, C306.2, C308.2, C309.2, C310.1, C311.2, C312.2, C313.2, C314.1, C315.2, C327.2, C330.2, R305.1, U301.5 (VS+), U301.6 (VS+), U301.7 (VS+), U301.8 (VS+), U302.4 (V+), U303.2 (AVDD), U303.7 (AVDD), U303.10 (AVDD), U303.12 (AVDD), U303.42 (AVDD); also elsewhere on the board
/ADC/1V0: C320.1, C323.1, C326.2, TP304.1 (1_1), U302.1, U302.2 (-), U303.44 (VREFN), U303.45 (VREFN)
/ADC/2V5: C307.1, C334.1, C336.1, TP303.1 (1_1), U301.9 (V_{ocm}), U302.6 (-), U302.7, U303.46 (VMID)
/ADC/4V0: C319.2, C322.2, C326.1, TP302.1 (1_1), U302.13 (-), U302.14, U303.47 (VREFP), U303.48 (VREFP)
/ADC/4V1: RV301.1, RV302.1, RV303.1, U302.8, U302.9 (-)
/ADC/ADC.CLK_IN: JP303.2 (B), R310.1, U303.40 (CLK)
/ADC/CLK.BAC: JP303.1 (A); also elsewhere on the board
/ADC/CLK.EN: U305.1 (Enable); also elsewhere on the board
/ADC/DOUT: R308.2; also elsewhere on the board
/ADC/FSO: R309.2; also elsewhere on the board
/ADC/SCLK: R306.2; also elsewhere on the board
/ADC/SYNC: U303.20 (SYNC); also elsewhere on the board
/ADC/Signal.In: U301.2 (+A); also elsewhere on the board
GND: C301.1, C302.1, C303.2, C304.2, C305.2, C306.1, C307.2, C308.1, C309.1, C310.2, C311.1, C312.1, C313.1, C314.2, C315.1, C319.1, C320.2, C321.1, C322.1, C323.2, C324.1, C325.1, C327.1, C328.1, C329.1, C330.1, C331.1, C332.2, C333.1, C334.2, C335.1, C336.2, C337.1, C338.1, C339.1, R303.2, R307.2, R311.2, RV302.3, RV303.3, U301.13 (VS-), U301.14 (VS-), U301.15 (VS-), U301.16 (VS-), U301.17 (EP), U302.11 (V-), U303.1 (AGND), U303.3 (AGND), U303.6 (AGND), U303.9 (AGND), U303.11 (AGND), U303.19 (DGND), U303.22 (DGND), U303.33 (DGND), U303.36 (DGND), U303.38 (DGND), U303.39 (AGND), U303.41 (AGND), U304.2 (A), U305.2 (GND); also elsewhere on the board
unnamed: JP301.1 (A), R303.1, U303.13 (~REF.EN)
unnamed: JP302.1 (A), R307.1
unnamed: JP302.2 (B), U303.8 (RBIAS)
unnamed: R311.1, RV301.3
unnamed: R301.1, U301.10 (+)
unnamed: R302.1, U301.11 (-)
unnamed: RV303.2, U302.3 (+)
unnamed: RV302.2, U302.5 (+)
unnamed: R305.2, U302.10 (+), U304.1 (K)
unnamed: RV301.2, U302.12 (+)
unnamed: C317.2, C318.1, R302.2, U303.4 (AINN)
unnamed: C316.2, C317.1, R301.2, U303.5 (AINP)
unnamed: R308.1, U303.30 (DOUT)
unnamed: R309.1, U303.32 (FSO)
unnamed: TP301.1 (1_1), U303.21 (OTR)
unnamed: R304.2, U303.15 (RPULLUP)
unnamed: R306.1, U303.28 (SCLK)
unnamed: C338.2, U303.43 (VCAP)
unnamed: R310.2, U305.3 (Output)
VCOM: C316.1, C318.2, U301.3 (-A); also elsewhere on the board

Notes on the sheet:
Power Symbols
5Vpp
Default Soldered
Voltage Reference
TODO: Check Trim-Potentiometer Footprint with real component
Sampling

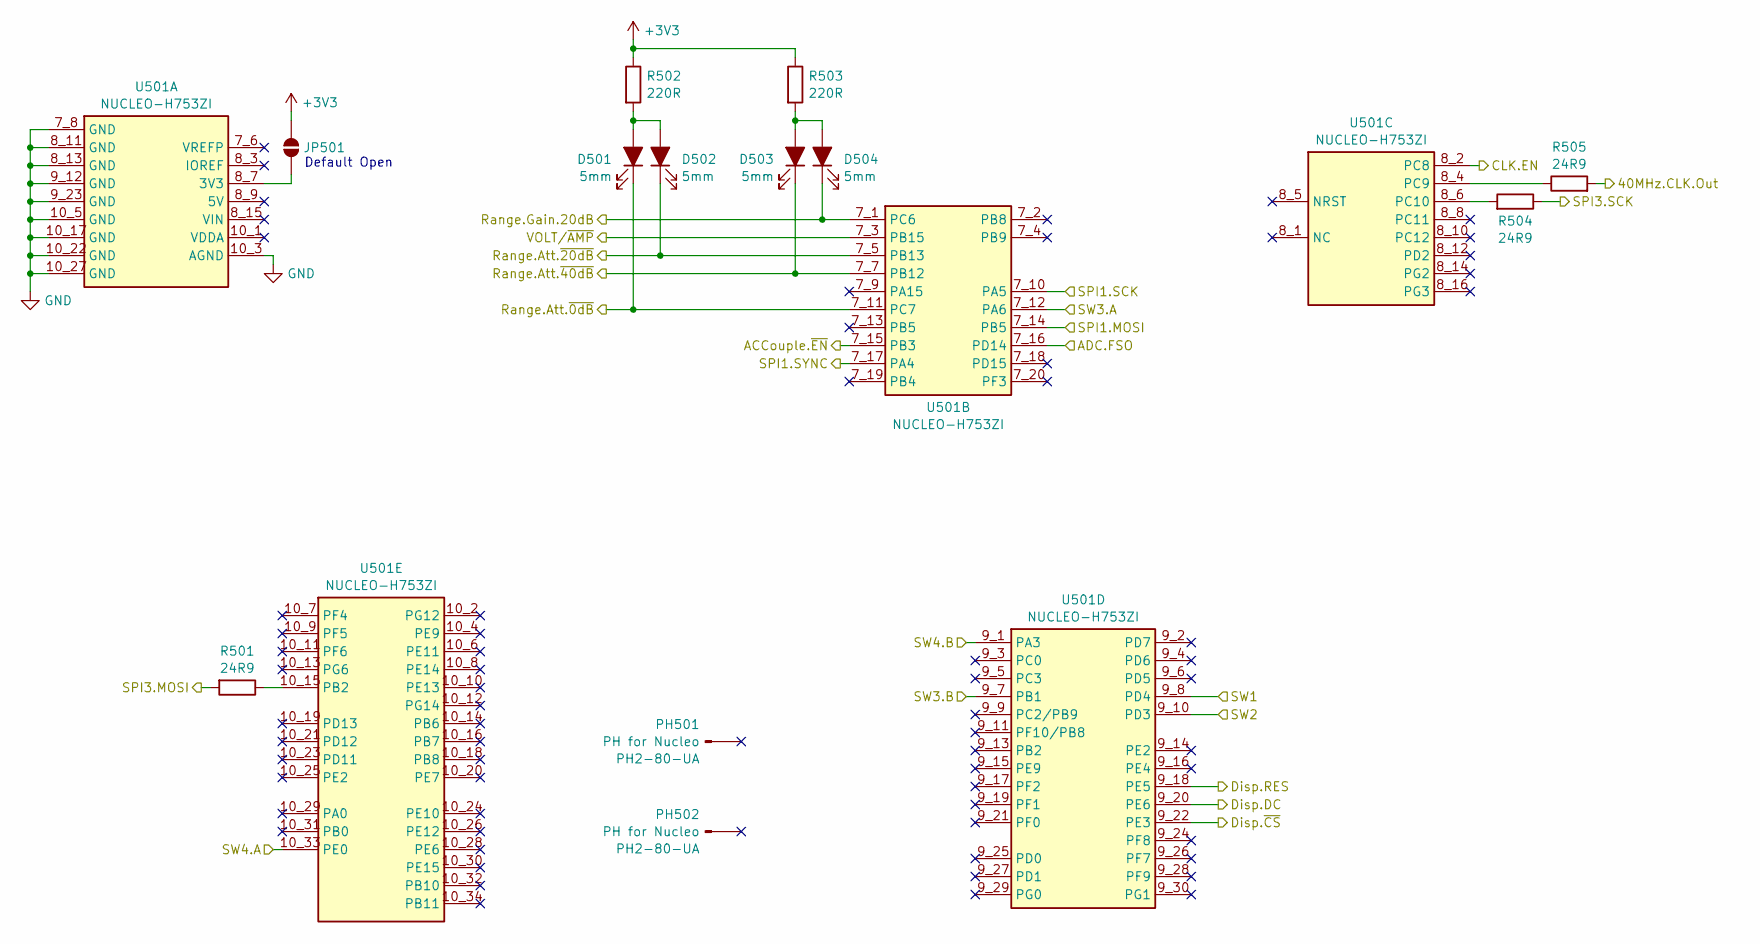
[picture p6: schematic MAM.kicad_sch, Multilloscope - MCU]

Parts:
D501, D502, D503, D504: 5mm; LED_D5.0mm; DigikeyPN N/A
JP501: SolderJumper_2_Open; SolderJumper-2_P1.3mm_Open_RoundedPad1.0x1.5mm; DigikeyPN N/A
PH501, PH502: PH for Nucleo; DigikeyPN 2057-PH2-80-UA-ND
R501, R504, R505: 24R9; R_0603_1608Metric_Pad0.98x0.95mm_HandSolder; DigikeyPN YAG4511CT-ND
R502, R503: 220R; R_Axial_DIN0207_L6.3mm_D2.5mm_P10.16mm_Horizontal; DigikeyPN N/A
U501: NUCLEO-H753ZI; MODULE_NUCLEO-H753ZI; DigikeyPN N/A

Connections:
+3V3: JP501.1 (A), R502.1, R503.1; also elsewhere on the board
/ADC/CLK.BAC: R505.2; also elsewhere on the board
/ADC/CLK.EN: U501.8_2 (PC8); also elsewhere on the board
/ADC/DOUT: U501.7_14 (PB5); also elsewhere on the board
/ADC/FSO: U501.7_16 (PD14); also elsewhere on the board
/ADC/SCLK: U501.7_10 (PA5); also elsewhere on the board
/ADC/SYNC: U501.7_17 (PA4); also elsewhere on the board
/Inputs/0dBAtten.~EN: D501.1 (K), U501.7_11 (PC7); also elsewhere on the board
/Inputs/20dBGain.EN: D504.1 (K), U501.7_1 (PC6); also elsewhere on the board
/Inputs/-20dBAtten.~EN: D502.1 (K), U501.7_5 (PB13); also elsewhere on the board
/Inputs/-40dBAtten.~EN: D503.1 (K), U501.7_7 (PB12); also elsewhere on the board
/Inputs/ACCouple.~EN: U501.7_15 (PB3); also elsewhere on the board
/Inputs/VOLT/~AMP: U501.7_3 (PB15); also elsewhere on the board
/Measurement and Analysis Module/Disp.DC: U501.9_20 (PE6); also elsewhere on the board
/Measurement and Analysis Module/Disp.RES: U501.9_18 (PE5); also elsewhere on the board
/Measurement and Analysis Module/Disp.~CS: U501.9_22 (PE3); also elsewhere on the board
/Measurement and Analysis Module/SPI3.MOSI: R501.2; also elsewhere on the board
/Measurement and Analysis Module/SPI3.SCK: R504.1; also elsewhere on the board
/Measurement and Analysis Module/SW1: U501.9_8 (PD4); also elsewhere on the board
/Measurement and Analysis Module/SW2: U501.9_10 (PD3); also elsewhere on the board
/Measurement and Analysis Module/SW3.A: U501.7_12 (PA6); also elsewhere on the board
/Measurement and Analysis Module/SW3.B: U501.9_7 (PB1); also elsewhere on the board
/Measurement and Analysis Module/SW4.A: U501.10_33 (PE0); also elsewhere on the board
/Measurement and Analysis Module/SW4.B: U501.9_1 (PA3); also elsewhere on the board
GND: U501.7_8 (GND), U501.8_11 (GND), U501.8_13 (GND), U501.9_12 (GND), U501.9_23 (GND), U501.10_3 (AGND), U501.10_5 (GND), U501.10_17 (GND), U501.10_22 (GND), U501.10_27 (GND); also elsewhere on the board
unnamed: D501.2 (A), D502.2 (A), R502.2
unnamed: D503.2 (A), D504.2 (A), R503.2
unnamed: JP501.2 (B), U501.8_7 (3V3)
unnamed: R505.1, U501.8_4 (PC9)
unnamed: R504.2, U501.8_6 (PC10)
unnamed: R501.1, U501.10_15 (PB2)

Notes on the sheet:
Default Open

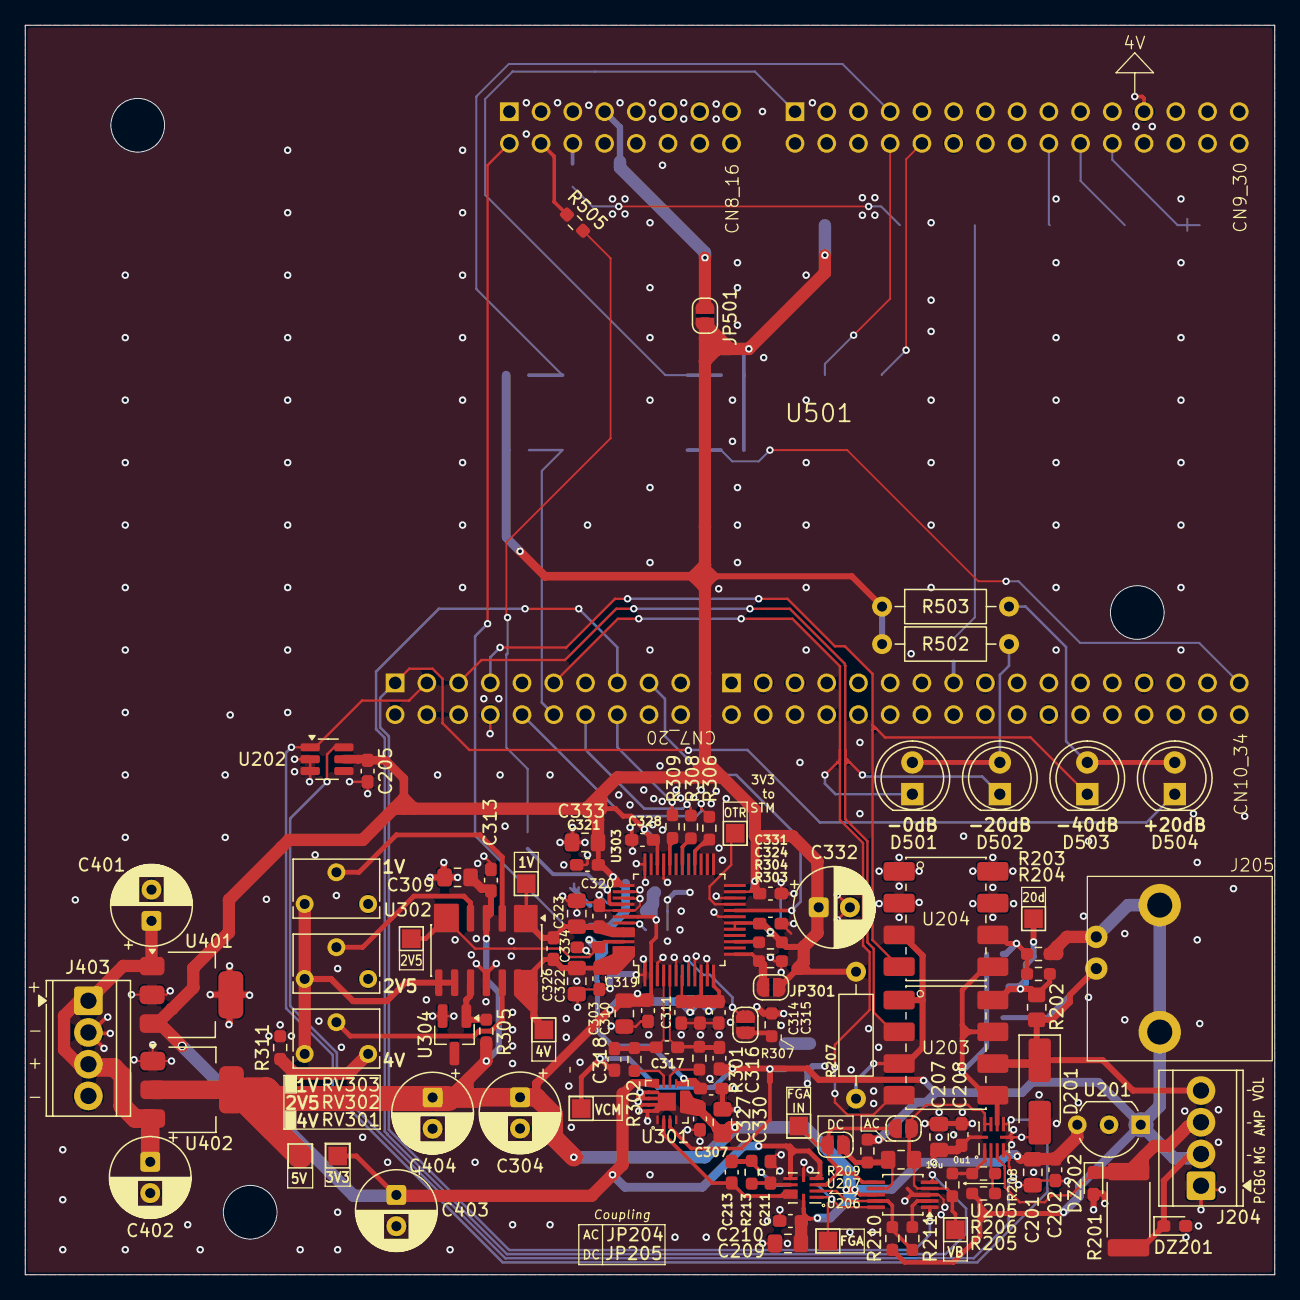
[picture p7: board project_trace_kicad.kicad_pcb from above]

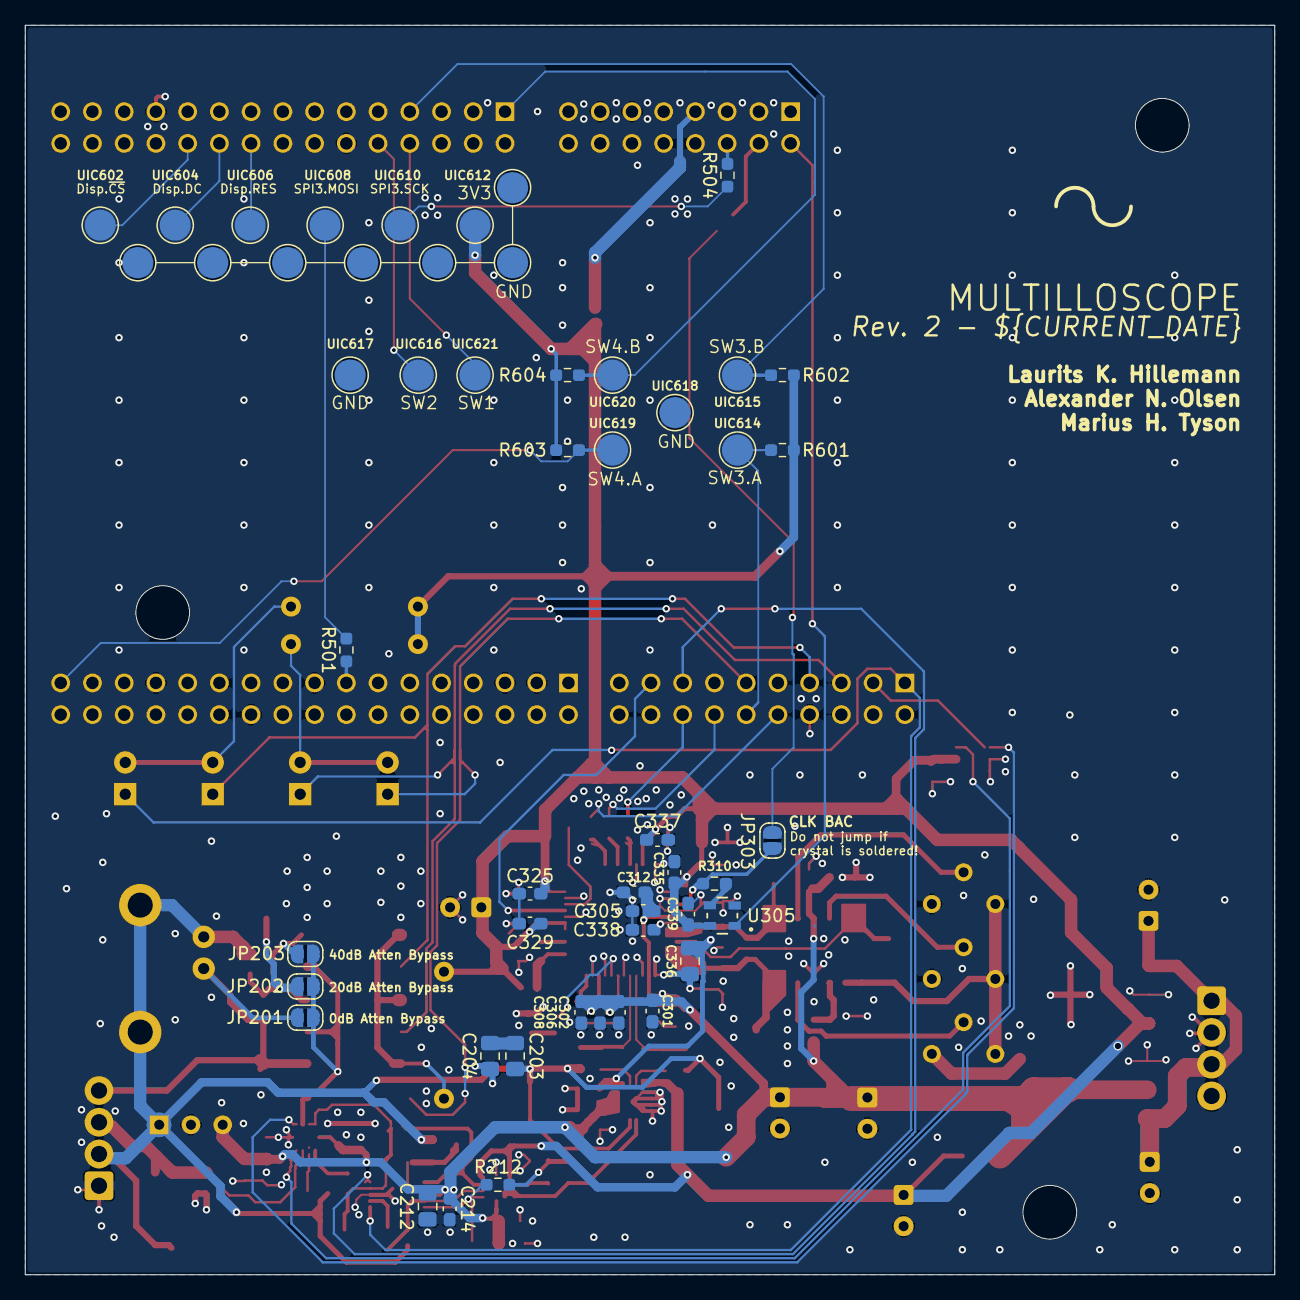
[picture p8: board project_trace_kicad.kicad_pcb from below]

Board: 4 copper layers, 100.0 x 100.0 mm, 162 parts (51 on the bottom side), 77 nets.

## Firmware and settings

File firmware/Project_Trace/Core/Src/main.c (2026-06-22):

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
/* Includes ------------------------------------------------------------------*/
#include "main.h"

/* USER CODE BEGIN Includes */
#include <stdio.h>
#include <stm32h7xx_hal.h>
#include <stdint.h>
#include <menu_system.h>
#include <graphics.h>


#include <adc.h>
#include <hal_oled.h>
#include <hal_signal_path.h>
#include <test_suite.h>
#include <sample_buffer.h>

#include <serialization.h>

#include <assert.h>

/* USER CODE END Includes */

/* USER CODE BEGIN PD */
//#define RUN_TESTS
/* USER CODE END PD */


SPI_HandleTypeDef hspi1;
SPI_HandleTypeDef hspi3;
DMA_HandleTypeDef hdma_spi1_rx;
DMA_HandleTypeDef hdma_spi3_tx;

TIM_HandleTypeDef htim1;
TIM_HandleTypeDef htim2;
TIM_HandleTypeDef htim3;
TIM_HandleTypeDef htim8;

UART_HandleTypeDef huart3;

void SystemClock_Config(void);
static void MX_GPIO_Init(void);
static void MX_DMA_Init(void);
static void MX_SPI3_Init(void);
static void MX_TIM2_Init(void);
static void MX_SPI1_Init(void);
static void MX_TIM3_Init(void);
static void MX_USART3_UART_Init(void);
static void MX_TIM8_Init(void);
static void MX_TIM1_Init(void);
/* USER CODE BEGIN 0 */
extern SampleBuffer sample_buffer;

int __io_putchar(int ch)
  {
   uint8_t c[1];
   c[0] = ch & 0x00FF;
   HAL_UART_Transmit(&huart3, &*c, 1, HAL_MAX_DELAY);
   return ch;
  }
/* USER CODE END 0 */

/**
  * @brief  The application entry point.
  * @retval int
  */
int main(void)
{
  /* MCU Configuration--------------------------------------------------------*/

  /* Reset of all peripherals, Initializes the Flash interface and the Systick. */
  HAL_Init();

  /* Configure the system clock */
  SystemClock_Config();

  /* Initialize all configured peripherals */
  MX_GPIO_Init();
  MX_DMA_Init();
  MX_SPI3_Init();
  MX_TIM2_Init();
  MX_SPI1_Init();
  MX_TIM3_Init();
  MX_USART3_UART_Init();
  MX_TIM8_Init();
  MX_TIM1_Init();
  /* USER CODE BEGIN 2 */
  //HAL_MspInit();
  //HAL_SPI_MspInit(&hspi1);


  printf("Hello, There!\r\n");
#ifdef RUN_TESTS
  printf("Running Tests!\r\n");


  //test_suite();
  while(1){}
#endif

  //__disable_irq();

  printf("Init Signal Path\n");
  hal_signal_path_init();
  hal_signal_path_attenuator_set(SignalPathAtten_0db);
  hal_signal_path_accouple_en(0);

  sample_buffer_init(&sample_buffer, 12500000); // TODO: use precise sample-rate
  printf("Init ADC\n");
  adc_init();

  printf("Init OLED\n");
  hal_oled_init();
  printf("Init Menu\n");
  menu_init();

  printf("Start ADC CLK\n");
  HAL_TIM_PWM_Start(&htim8, TIM_CHANNEL_4);


  //const char* header_labels[1] = { "x" };
  //(void)ser_file_write_csv_header(stdout, header_labels, 1);

  //__enable_irq();
  /* USER CODE END 2 */

  /* Infinite loop */
  /* USER CODE BEGIN WHILE */
  graphics_draw_rect_rel(5, 5, 10, 10);
  graphics_draw_text(8, 8, "address me");

  printf("Enter Loop\n");
  while (1)
  {
    /* USER CODE END WHILE */

    /* USER CODE BEGIN 3 */

//	  hal_oled_update_screen();
//	  for (uint32_t i = 0; i < 10000000LL; i++){}
//	  printf("Hi!\r\n");

  }
  /* USER CODE END 3 */
}

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
/* USER CODE BEGIN 4 */
void HAL_SPI_RxCpltCallback(SPI_HandleTypeDef *hspi)
{
	//printf("HAL_SPI_RxCpltCallback\n");

    if (hspi->Instance == SPI1){
        __disable_irq();
    	adc_dma_done();
    	__enable_irq();
    }
    else if (hspi->Instance == SPI3){
    	// TODO add display SPI3
    }
}

void HAL_SPI_RxErrorCallback(SPI_HandleTypeDef *hspi) {
	printf("HAL_SPI_RxErrorCallback\n");
	(void) hspi;
}

/* USER CODE END 4 */
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


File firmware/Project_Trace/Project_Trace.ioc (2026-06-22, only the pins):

Mcu.UserName=STM32H753ZITx
PA0.GPIO_Label=SW4.A
PA0.Signal=S_TIM2_CH1_ETR
PA3.GPIO_Label=SW4.B
PA3.Signal=S_TIM2_CH4
PA4.GPIO_Label=SPI1.SYNC
PA4.Signal=GPIO_Output
PA5.GPIO_Label=SPI1.SCK
PA5.Signal=SPI1_SCK
PA6.GPIO_Label=SW3.A
PA6.Signal=S_TIM3_CH1
PB12.GPIO_Label=Range.att.40db
PB12.Signal=GPIO_Output
PB13.GPIO_Label=Range.att.20db
PB13.Signal=GPIO_Output
PB15.GPIO_Label=V/A.meter
PB15.Signal=GPIO_Output
PB2.GPIO_Label=SPI3.MOSI
PB2.Signal=SPI3_MOSI
PB5.GPIO_Label=SPI1.MOSI
PB5.Signal=SPI1_MOSI
PC10.GPIO_Label=SPI3.SCK
PC10.Signal=SPI3_SCK
PC6.GPIO_Label=Range.gain.20db
PC6.Signal=GPIO_Output
PC7.GPIO_Label=Range.att.0db
PC7.Signal=GPIO_Output
PC8.GPIO_Label=CLK.EN
PC8.Signal=GPIO_Output
PC9.Signal=S_TIM8_CH4
PD14.GPIO_Label=ADC.FS0
PD14.Signal=GPXTI14
PD3.GPIO_Label=SW2
PD3.Signal=GPIO_Input
PD4.GPIO_Label=SW1
PD4.Signal=GPIO_Input
PD8.Signal=USART3_TX
PD9.Signal=USART3_RX
PE3.GPIO_Label=Disp.CS
PE3.Signal=GPIO_Output
PE5.GPIO_Label=Disp.RES
PE5.Signal=GPIO_Output
PE6.GPIO_Label=Disp.DC
PE6.Signal=GPIO_Output

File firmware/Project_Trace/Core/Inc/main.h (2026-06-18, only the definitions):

#define Disp_CS_Pin GPIO_PIN_3
#define Disp_CS_GPIO_Port GPIOE
#define Disp_RES_Pin GPIO_PIN_5
#define Disp_RES_GPIO_Port GPIOE
#define Disp_DC_Pin GPIO_PIN_6
#define Disp_DC_GPIO_Port GPIOE
#define SW4_A_Pin GPIO_PIN_0
#define SW4_A_GPIO_Port GPIOA
#define SW4_B_Pin GPIO_PIN_3
#define SW4_B_GPIO_Port GPIOA
#define SPI1_SYNC_Pin GPIO_PIN_4
#define SPI1_SYNC_GPIO_Port GPIOA
#define SPI1_SCK_Pin GPIO_PIN_5
#define SPI1_SCK_GPIO_Port GPIOA
#define SW3_A_Pin GPIO_PIN_6
#define SW3_A_GPIO_Port GPIOA
#define SPI3_MOSI_Pin GPIO_PIN_2
#define SPI3_MOSI_GPIO_Port GPIOB
#define Range_att_40db_Pin GPIO_PIN_12
#define Range_att_40db_GPIO_Port GPIOB
#define Range_att_20db_Pin GPIO_PIN_13
#define Range_att_20db_GPIO_Port GPIOB
#define V_A_meter_Pin GPIO_PIN_15
#define V_A_meter_GPIO_Port GPIOB
#define ADC_FS0_Pin GPIO_PIN_14
#define ADC_FS0_GPIO_Port GPIOD
#define Range_gain_20db_Pin GPIO_PIN_6
#define Range_gain_20db_GPIO_Port GPIOC
#define Range_att_0db_Pin GPIO_PIN_7
#define Range_att_0db_GPIO_Port GPIOC
#define CLK_EN_Pin GPIO_PIN_8
#define CLK_EN_GPIO_Port GPIOC
#define SPI3_SCK_Pin GPIO_PIN_10
#define SPI3_SCK_GPIO_Port GPIOC
#define SW2_Pin GPIO_PIN_3
#define SW2_GPIO_Port GPIOD
#define SW1_Pin GPIO_PIN_4
#define SW1_GPIO_Port GPIOD
#define ACCoupleEnable_Pin GPIO_PIN_3
#define ACCoupleEnable_GPIO_Port GPIOB
#define SPI1_MOSI_Pin GPIO_PIN_5
#define SPI1_MOSI_GPIO_Port GPIOB

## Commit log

2026-03-12 Draft Input Section
    [AAAF.kicad_sch, Inputs.kicad_sch, project_trace_kicad.kicad_sch]
2026-03-12 Add TVS, Fixes to Ammeter
    Fix Ammeter OV Vulnerability
    Choose Ammeter Current-Sensing Resistor
    [Inputs.kicad_sch]
2026-03-12 Add TVS Diode to VCOM
    [Inputs.kicad_sch]
2026-03-16 Introduce basic design rules, tweak inputs
    [Inputs.kicad_sch, project_trace_kicad.kicad_pcb]
2026-03-17 Rushed Push Footprint Lib
    [DAQ_AC.kicad_sch, DAQ_DC.kicad_sch, Inputs.kicad_sch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]
2026-03-19 Added DAQ_AC and DAC
    [DAQ_AC.kicad_sch, Inputs.kicad_sch]
2026-03-19 Write doc on AC-ADC
2026-03-19 Changes to DAQ-AC and Inputs
    [DAQ_AC.kicad_sch, Inputs.kicad_sch]
2026-03-19 Create MAM Schematic
    [MAM.kicad_sch, project_trace_kicad.kicad_sch]
2026-03-19 Add power circuit
    [Power.kicad_sch, project_trace_kicad.kicad_sch]
2026-03-22 Add Decoupling, Fix Bugs
    [DAQ_AC.kicad_sch, Inputs.kicad_sch]
2026-03-25 Fix Mistakes, Reduce Scope, improve Flexibility
    [DAQ_AC.kicad_sch, Inputs.kicad_sch, Power.kicad_sch]
2026-03-26 Before Changes to Input Section
    [DAQ_AC.kicad_sch, Inputs.kicad_sch, Power.kicad_sch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]
2026-03-27 Add Pull-Up Network to Input
    (Sync up laptop)
    [DAQ_AC.kicad_sch, Inputs.kicad_sch]
2026-03-28 Change designators, Improve Input Circuit
    [DAQ_AC.kicad_sch, Inputs.kicad_sch, Power.kicad_sch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]
2026-03-29 Improve Inputs, Source Parts, Add Credits
    [DAQ_AC.kicad_sch, Inputs.kicad_sch, Power.kicad_sch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]
2026-03-30 Nucleo footprint created
2026-03-30 Nucleo symbol created
    [MAM.kicad_sch]
2026-03-30 Update ADC, TODOS
2026-03-30 Revert "Nucleo symbol created"
    This reverts commit 654da356d897b351af1e12bc90fe7be70eb3e4d8.
    [MAM.kicad_sch]
2026-03-30 Re-add Nucleo-Board Symbol to Library
2026-03-30 Op amp Footprint
2026-03-30 Lotsa Changes
    [DAQ_AC.kicad_sch, Inputs.kicad_sch, MAM.kicad_sch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]
2026-03-30 PCB start
    [project_trace_kicad.kicad_pcb]
2026-03-31 Fix Footprints, Add ADC Footpring, begin Layout
    [DAQ_AC.kicad_sch, Inputs.kicad_sch, project_trace_kicad.kicad_pcb]
2026-04-01 Implement AAAF, reintroduce differential driver.
    [DAQ_AC.kicad_sch, Inputs.kicad_sch]
2026-04-01 Fix Bug in Diffamp, update PCB
    [DAQ_AC.kicad_sch, Inputs.kicad_sch, project_trace_kicad.kicad_pcb]
2026-04-01 Skitse til første halvdel af trancing to input
    [project_trace_kicad.kicad_pcb]
2026-04-02 Work on PCB, Fix bugs, Improve noise performance
    [DAQ_AC.kicad_sch, Inputs.kicad_sch, Power.kicad_sch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]
2026-04-02 UI made, MAM updated with correct labels
    [DAQ_AC.kicad_sch, MAM.kicad_sch, UserInterface.kicad_sch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]
2026-04-02 Fix hardware-digital merge
    [MAM.kicad_sch, UserInterface.kicad_sch, project_trace_kicad.kicad_sch]
2026-04-03 Layout Broad Strokes, Fix STM32H7 Error
    [DAQ_AC.kicad_sch, Inputs.kicad_sch, MAM.kicad_sch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]
2026-04-03 power added to nucleo and GPIO for ranging/ac/dc added to Nucleo
    [MAM.kicad_sch, UserInterface.kicad_sch, project_trace_kicad.kicad_sch]
2026-04-03 Add missing Part-numers, Revise AC Coupling
    [DAQ_AC.kicad_sch, Inputs.kicad_sch, MAM.kicad_sch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]
2026-04-04 DigikeyPN added for Pinconnectors to Nucleo
    [MAM.kicad_sch]
2026-04-05 Address Review Comments
    [DAQ_AC.kicad_sch, Inputs.kicad_sch, Power.kicad_sch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]
2026-04-06 UI updated, CLK implemented, Parts labeled as Donotplace in power
    [DAQ_AC.kicad_sch, MAM.kicad_sch, Power.kicad_sch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]
2026-04-06 Fix main-merge
    [DAQ_AC.kicad_sch, UserInterface.kicad_sch, project_trace_kicad.kicad_sch]
2026-04-06 Before using stashed changes
    [DAQ_AC.kicad_sch, project_trace_kicad.kicad_pcb]
2026-04-06 Updates to PCB, Schematic Fixes
    [DAQ_AC.kicad_sch, Inputs.kicad_sch, project_trace_kicad.kicad_pcb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]
2026-04-06 Hierarchical pins for clk added, CLK resistance in MAM added
    [MAM.kicad_sch, project_trace_kicad.kicad_sch]
2026-04-06 Changes to PCB
    [project_trace_kicad.kicad_pcb]
2026-04-06 PN removed from items not to be ordered and BOM generated/updated
    [MAM.kicad_sch, UserInterface.kicad_sch, project_trace_kicad.csv]
2026-04-06 Further PCB development
    [MAM.kicad_sch, project_trace_kicad.kicad_pcb]
2026-04-06 ERC Checks & Bug-Fixing
    [DAQ_AC.kicad_sch, Inputs.kicad_sch, MAM.kicad_sch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]
2026-04-06 Symbols for Pin-ordering added to MAM
    [MAM.kicad_sch]
2026-04-06 Work on Layout
    [DAQ_AC.kicad_sch, project_trace_kicad.kicad_pcb]
2026-04-06 Work on PCB
    [MAM.kicad_sch, project_trace_kicad.kicad_pcb]
2026-04-06 Work on Layout + DRC Revision
    [project_trace_kicad.kicad_pcb]
2026-04-06 Partnumbers and BOM updated
    [Inputs.kicad_sch, MAM.kicad_sch, Power.kicad_sch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]
2026-04-06 Work on PCB + Silkscreen work
    [project_trace_kicad.kicad_pcb]
2026-04-06 Silk Screen Modifications
    [project_trace_kicad.kicad_pcb]
2026-04-06 Populate Drawing Sheet Information (PCB)
    [project_trace_kicad.kicad_pcb]
2026-04-06 final(?) Silkscreen
    [project_trace_kicad.kicad_pcb]
2026-04-07 Improvements to PCB
    [Inputs.kicad_sch, MAM.kicad_sch, project_trace_kicad.kicad_pcb]
2026-04-08 Fix Screw Terminal Clearance Issue
    [project_trace_kicad.kicad_pcb]
2026-04-08 Add Missing Power Connection to Nucleo
    [MAM.kicad_sch, project_trace_kicad.kicad_pcb]
2026-04-08 Rework started
    [DAQ_AC.kicad_sch, MAM.kicad_sch, project_trace_kicad.kicad_pcb]
2026-04-09 Fix inconsistency with ADC datasheet, fix DRC Errors
    [DAQ_AC.kicad_sch, MAM.kicad_sch, project_trace_kicad.kicad_pcb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]
2026-04-09 Improvements to Power layout and Silkscreen
    [DAQ_AC.kicad_sch, Inputs.kicad_sch, MAM.kicad_sch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]
2026-04-09 Layout Improvements, Silkscreen Improvements
    [project_trace_kicad.kicad_pcb]
2026-04-09 Pre Diffamp
    [DAQ_AC.kicad_sch, project_trace_kicad.kicad_pcb]
2026-04-09 footprint ADA4950
2026-04-09 Implement new DiffAmp, Small Improvements
    [DAQ_AC.kicad_sch, UserInterface.kicad_sch, project_trace_kicad.kicad_pcb]
2026-04-10 Changes to Digital
    [DAQ_AC.kicad_sch, MAM.kicad_sch, UserInterface.kicad_sch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]
2026-04-11 Hardware NSS renamed to SYNC
    [MAM.kicad_sch, project_trace_kicad.kicad_sch]
2026-04-11 Adjust Layer Thickness, fix insignificant DRC Warnings
    [DAQ_AC.kicad_sch, Inputs.kicad_sch, project_trace_kicad.kicad_pcb]
2026-04-11 Clean Redundant TODO items
    [Inputs.kicad_sch]
2026-04-14 Fix wrong partno, add debug LED
    [MAM.kicad_sch, Power.kicad_sch, project_trace_kicad.kicad_pcb]
2026-04-16 Unfinished change of UI connectivity
    [DAQ_AC.kicad_sch, Inputs.kicad_sch, MAM.kicad_sch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]
2026-04-16 Review 1 issues adressed
    [DAQ_AC.kicad_sch, MAM.kicad_sch, Power.kicad_sch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]
2026-04-18 Address items of internal review
    [DAQ_AC.kicad_sch, Inputs.kicad_sch, MAM.kicad_sch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]
2026-04-19 Small Fixes, Fabrication File Check
    [DAQ_AC.kicad_sch, MAM.kicad_sch, UserInterface.kicad_sch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]
2026-04-19 small spacing on sw lines and gerber files generated
    small spacing on sw lines and gerber files generated
    [project_trace_kicad.kicad_pcb]
2026-04-19 Before First Submission
    [project_trace_kicad.csv, project_trace_kicad.kicad_pcb]
2026-04-20 GPIO fuctions first attempt
    Den skal helt klart rettes og der er ikke nogen tests, men her er nogen functioner
2026-04-27 Add Unit Testing & Fixpoint
    [main.c]
2026-05-04 Add Meas, Calibration, Expand fixpoint and complex
2026-05-07 ADC and Pinouts coded and configured
    Somewhat broken
    [Project_Trace.ioc, adc.c, main.c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]
2026-06-09 Begin sample buffer implementation, rename file
2026-06-09 Update Meas API according to new Samplebuf format
2026-06-11 Fix bug in USB printing, expand serialization
    [adc.c]
2026-06-11 Fix Bug in signal path HAL
    [hal_signal_path.c, main.c]
2026-06-11 Create routines for manual math and framebuffer tests
2026-06-14 Fix uninitialized variable in ADC
    [adc.c]
2026-06-14 Improved code for sample_buffer
2026-06-15 Fixed FFT, fixed sqrt function in fixedpoint library
    [plotting.c]
2026-06-17 Fix bug with SYNC pin, Fix bug in Atten
    [adc.c, hal_signal_path.c, main.c]
2026-06-17 Change ADC to Circular Mode, Achieve data output
2026-06-18 Fix bugs in the signal path
    [Project_Trace.ioc, adc.c, hal_signal_path.c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]
2026-06-20 Update calibration model, Fix signal processing bugs
    [adc.c, menu_system.c, plotting.c]
2026-06-21 Fix uninitialized buffer, make some parameters const
    [adc.c, main.c, menu_system.c]

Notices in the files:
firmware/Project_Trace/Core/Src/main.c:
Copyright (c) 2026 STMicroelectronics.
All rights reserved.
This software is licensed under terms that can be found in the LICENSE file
